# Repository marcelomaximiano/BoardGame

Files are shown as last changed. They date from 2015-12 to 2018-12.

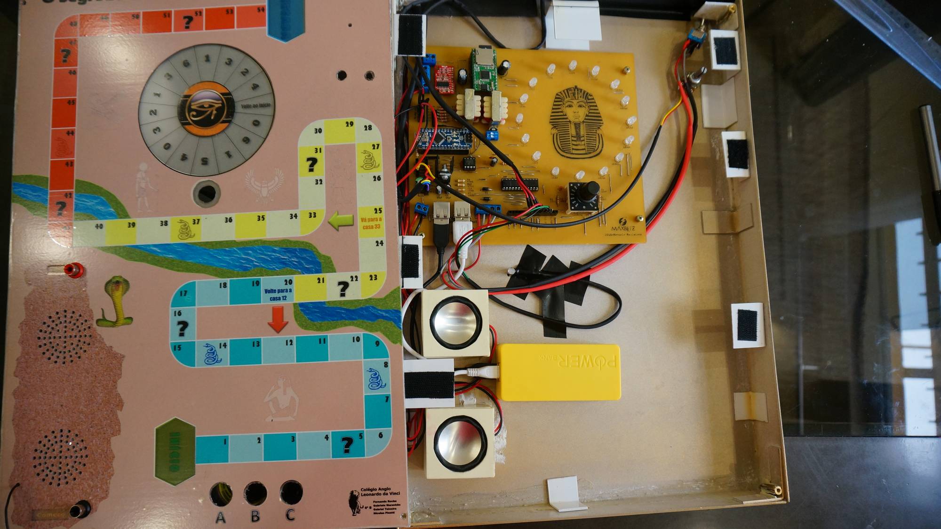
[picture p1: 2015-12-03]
pictures/17-Assembly.jpg

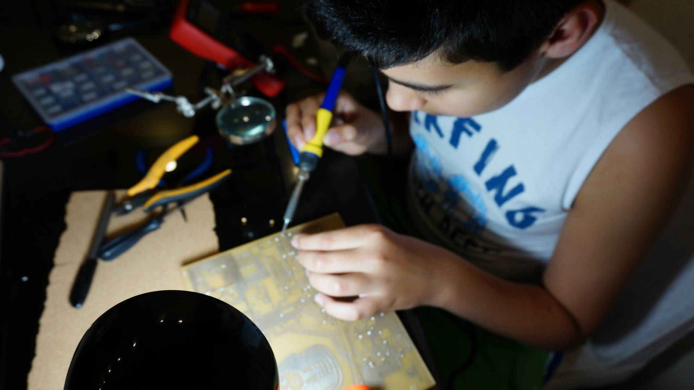
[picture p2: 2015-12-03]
pictures/05-Nick_Soldering.jpg

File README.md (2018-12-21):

# BoardGame
Arduino Board Game: The Pyramid's Secret
<br>
Egypt-themed board game powered by an Arduino Nano, that controls the roulette wheel leds, push buttons, sound player (voices and music), LCD display, etc.

Arduino Project Hub
https://tinyurl.com/arduinopyramidsecret

Make Magazine's article:
https://makezine.com/2016/04/13/these-middle-schoolers-built-custom-arduino-board-game-explore-ancient-egypt/

Videos:
https://www.youtube.com/watch?v=22LTTz00c54
<br>
https://www.youtube.com/watch?v=dJfBCsZCKEY

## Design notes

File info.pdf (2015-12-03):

### O Segredo da Pirâmide

Procuro sempre despertar a curiosidade nos meus filhos, e estimular a ideia de pensar em soluções sem limites: o importante é pensar livremente e criar uma solução, depois, correr atrás do conhecimento necessário para fazer a implementação, afinal a Internet é uma fonte inesgotável de informação, conectando-nos a outros “curiosos” pelo mundo afora, permitindo trocar experiências e inventar coisas novas.

Quando meu filho mais novo, Nícolas de 11 anos, surgiu com a demanda de fazer jogo de tabuleiro para a feira de ciências da escola, logo pensei que seria uma boa oportunidade de incentivar a usar eletrônica. A ideia inicial era só de substituir o dado convencional por um eletrônico com leds. Como o Nícolas é muito criativo, logo começou a “incrementar” a ideia, sugerindo fazer no lugar do dado eletrônico, uma roleta com motor elétrico. Fiz alguns testes e sugeri que seria melhor fazer com leds. Ele gostou da ideia e o escopo estava definido.

Quando as outras crianças do grupo dele se juntaram para começar a fazer o trabalho, orientei-os a projetar um jogo de tabuleiro tradicional, e depois acrescentar a roleta. Bem, a criatividade do Nícolas acabou por “contaminar” os coleguinhas e as ideias começaram a brotar. Como não quis cercear a criatividade deles, o escopo acabou aumentando muito, e ficou um pouquinho mais complexo...

Mas depois de muito trabalho, tudo deu certo e foi um sucesso.

Seguem os detalhes técnicos do projeto:

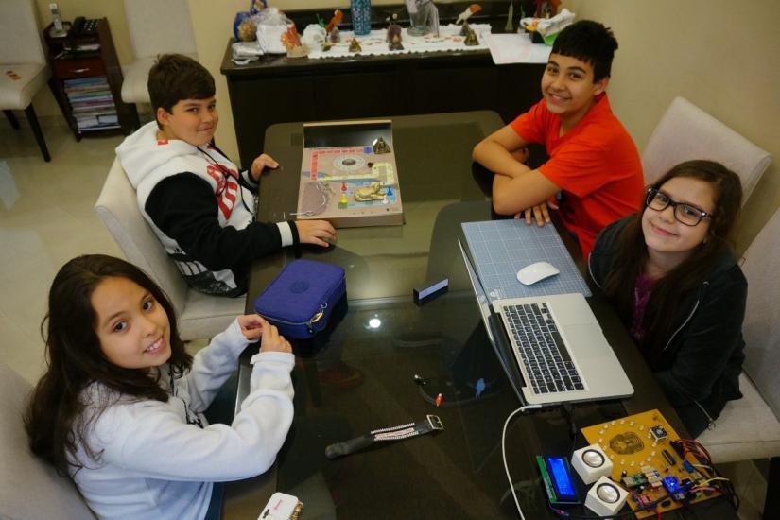
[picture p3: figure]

Equipe-> esquerda: Gabriel Teixeira, Fernanda Rocha / Direita: Nícolas P. Maximiano, Gabriela Maranhão

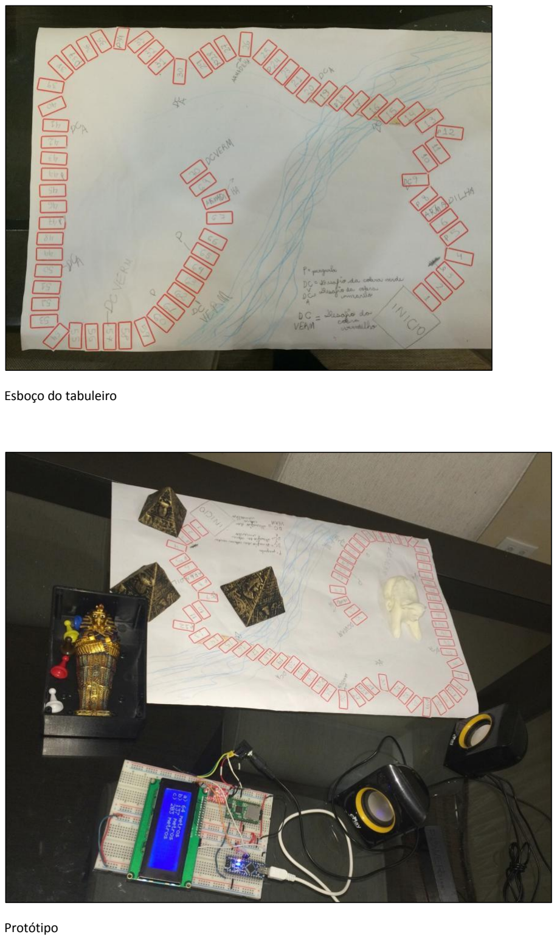
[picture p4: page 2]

Esboço do tabuleiro

Protótipo

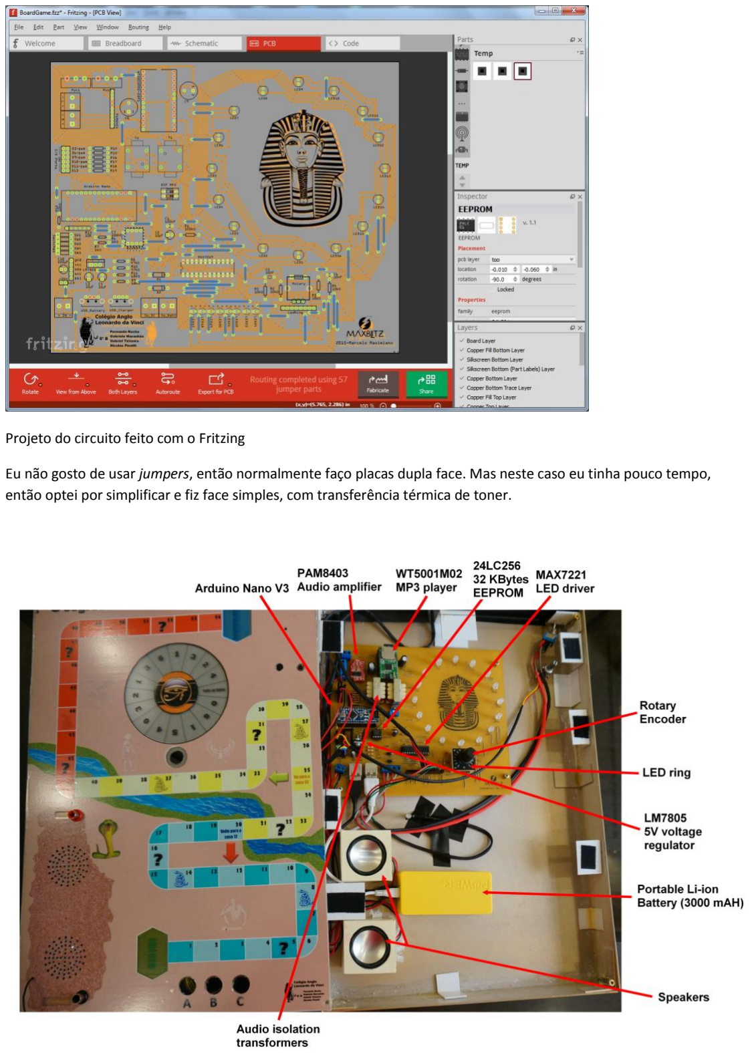
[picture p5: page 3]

Projeto do circuito feito com o Fritzing

Eu não gosto de usar jumpers, então normalmente faço placas dupla face. Mas neste caso eu tinha pouco tempo, então optei por simplificar e fiz face simples, com transferência térmica de toner.

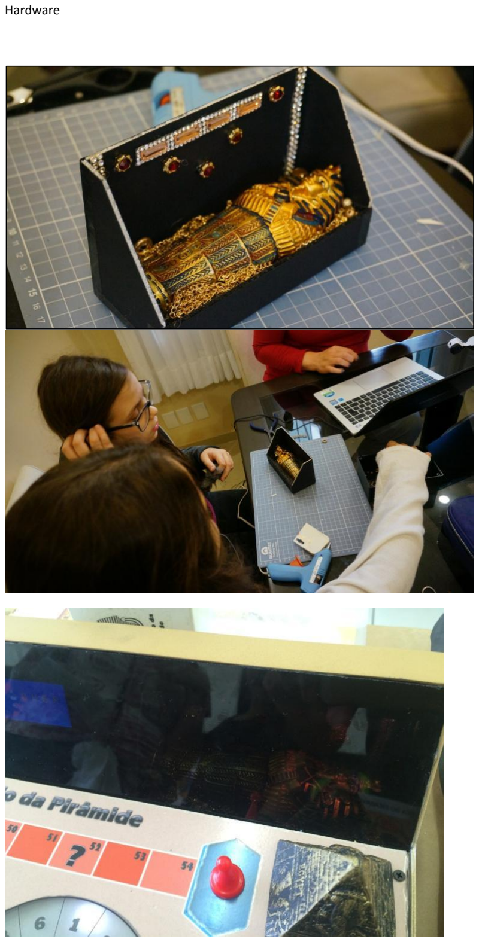
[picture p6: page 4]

Hardware

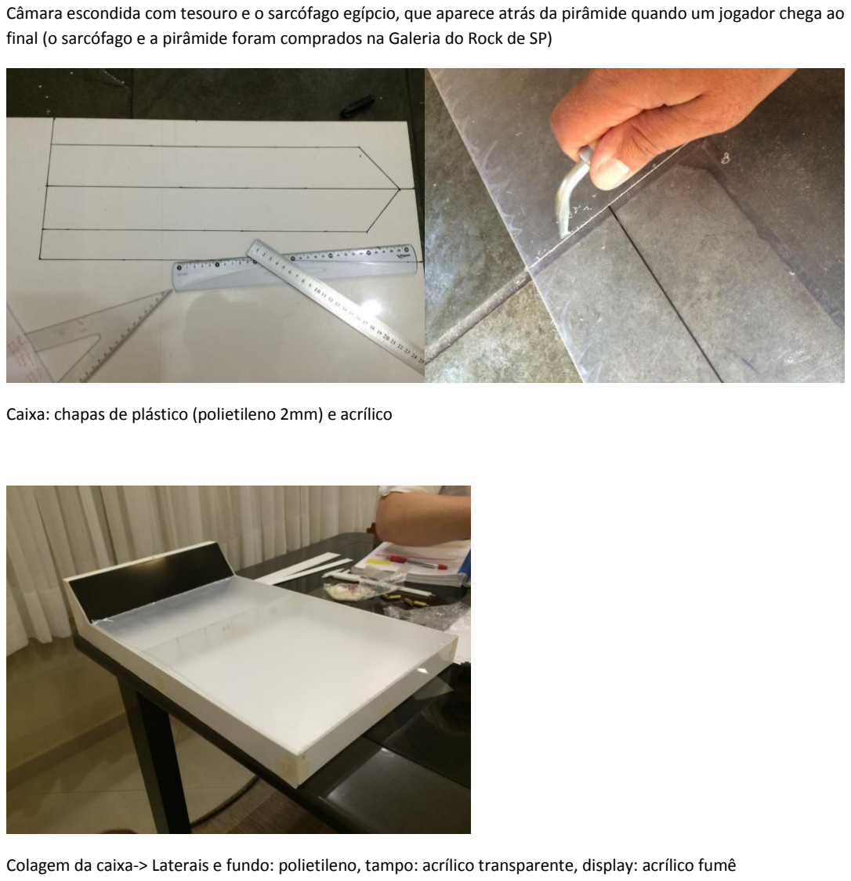
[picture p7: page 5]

Câmara escondida com tesouro e o sarcófago egípcio, que aparece atrás da pirâmide quando um jogador chega ao final (o sarcófago e a pirâmide foram comprados na Galeria do Rock de SP)

Caixa: chapas de plástico (polietileno 2mm) e acrílico

Colagem da caixa-> Laterais e fundo: polietileno, tampo: acrílico transparente, display: acrílico fumê

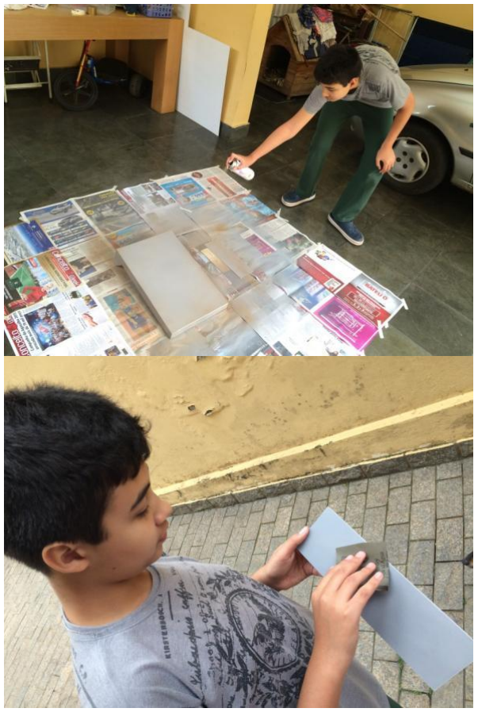
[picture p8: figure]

Pintura

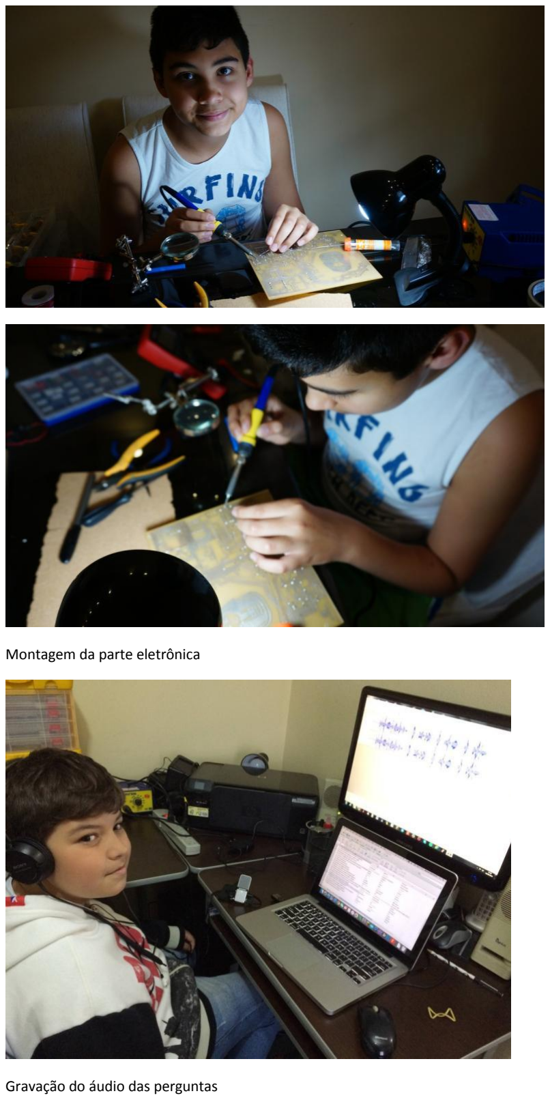
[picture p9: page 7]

Montagem da parte eletrônica

Gravação do áudio das perguntas

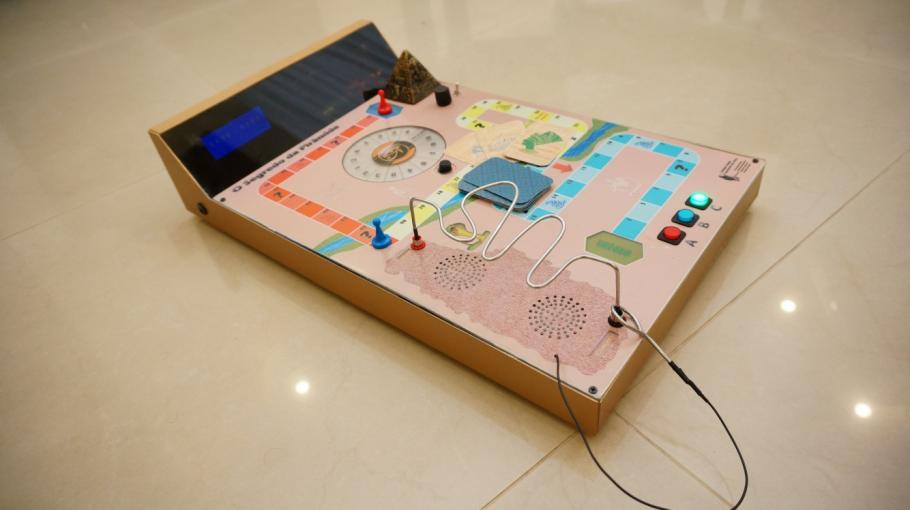
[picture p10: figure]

Desenho do tabuleiro feito no Word e impresso em adesivo vinil

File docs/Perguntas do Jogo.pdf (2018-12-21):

Num | ROM | Page | MP3 Index Time | | Categoria | Pergunta | A | B | C
0 | 00000 | 00001 | 1 | 2 | Fácil | Em qual região fica o Egito? | Norte da África | Oriente Médio | Sul da Ásia
1 | 00160 | 00001 | 2 | 3 | Fácil | Qual é a maior das pirâmides de Gizé? | Quéfren | Miquerinos | Quéops
2 | 00320 | 00001 | 5 | 2 | Fácil | O que é um escaravelho? | Uma pedra preciosa | Um inseto | Um tipo de rato
3 | 00480 | 00001 | 10 | 2 | Fácil | Os Faraós eram : | Amáveis | Soberanos | Legais
4 | 00640 | 00001 | 14 | 3 | Fácil | Quando um egípcio morria ele era: | Cremado | Mumificado | Jogado no Rio Nilo
5 | 00800 | 00002 | 19 | 4 | Fácil | Qual o nome da Raça da Cobra mais perigosa do Egito? | Naja | Sucuri | Titinaboa
6 | 00960 | 00002 | 25 | 2 | Fácil | O faraó era considerado um: | Um rei | Um deus vivo | Uma pessoa importante
7 | 01120 | 00002 | 27 | 3 | Fácil | O que significava o escaravelho para os egípcios? | Renascimento | Guerra | Fortuna
8 | 01280 | 00002 | 28 | 2 | Fácil | Qual era o tipo de governo do egito antigo? | Monarquia | Teocracia | Democracia
9 | 01440 | 00002 | 30 | 4 | Fácil | Qual era o orgão que não era removido durante a mumificação? | Fígado | Cérebro | Coração
10 | 01600 | 00003 | 35 | 2 | Fácil | Qual deus tem cabeça de falcão? | Anúbis | Hórus | Konshu
11 | 01760 | 00003 | 40 | 4 | Fácil | Quem foi falsamente acusado de quebrar o nariz da Esfinge? | Napoleão Bonaparte | Marco Polo | Caesar
12 | 01920 | 00003 | 45 | 3 | Fácil | Qual animal era considerado sagrado? | Gato | Falcão | Chacal
13 | 02080 | 00003 | 47 | 3 | Fácil | Quem era o Deus dos Mortos? | Anúbis | Sobek | Hórus
14 | 02240 | 00003 | 4 | 3 | Média | Para o quê serviam as pirâmides? | Moradia para os faráosTúmulos para faraós Cultos religiosos
15 | 02400 | 00004 | 7 | 3 | Média | O exército do Egito Antigo era formado por: | Soldados Profissionais Escravos | | Pessoas Comuns
16 | 02560 | 00004 | 8 | 3 | Média | Qual o Nome do principal deus do Egito? | Rá | Anubís | Osirís
17 | 02720 | 00004 | 13 | 2 | Média | Quando surgiu a civilização Egipcia? | 30.000 A.C. | 100 A.C. | 3.000 a.C
18 | 02880 | 00004 | 15 | 3 | Média | O nome do protetor das pirâmides? | Esfinge | Anubís | Gib
19 | 03040 | 00004 | 16 | 2 | Média | Onde fica o baixo Egito? | Ao norte do Egito | Ao Sul do Egito | Ao oeste do Egito
20 | 03200 | 00005 | 17 | 4 | Média | O que significa a palavra hieróglifos ? | Escrita dos homens | Escrita sagrada | Escrita do deserto
21 | 03360 | 00005 | 21 | 4 | Média | Quem era o faraó do Egito durante o êxodo dos hebreus? | Seti I | Ramses II | Ramses I
22 | 03520 | 00005 | 22 | 3 | Média | Os Medjay endureciam seus cabelos com: | Cera | Lodo | Barro
23 | 03680 | 00005 | 23 | 3 | Média | Com qual idade Tutancamun se tornou Faraó ? | 10 anos | 9 anos | 11 anos
24 | 03840 | 00005 | 24 | 3 | Média | Qual era o principal problema de saúde dos egipcios? | Problemas RespiratóriosEbola | | Tuberculóse
25 | 04000 | 00006 | 33 | 2 | Média | Quem era o deus do céu? | Rá | Maet | Hórus
26 | 04160 | 00006 | 36 | 3 | Média | Qual era a cor original das pirâmides de Gizé? | Amarela | Cor de areia | Branca
27 | 04320 | 00006 | 37 | 4 | Média | Quantos anos durou a Antiga Civilização Egipcia? | 3000 anos | 1200 anos | 800 anos
28 | 04480 | 00006 | 38 | 3 | Média | Quantas pirâmides foram encontradas no Egito? | 20 | 45 | Mais de 100
29 | 04640 | 00006 | 39 | 5 | Média | O quê os agricultores egípcios faziam na época da cheia do Nilo? | Viajavam de férias | Trabalhavam nos monumentos Iam para escolas de agricultura
30 | 04800 | 00007 | 41 | 3 | Média | Quem foi o último faraó do Egito Antigo? | Cesarión | Tutankamon | Tutmés III
31 | 04960 | 00007 | 42 | 4 | Média | Quem foi o primeiro faraó a ser enterrado no Vale dos Deuses? | Amenófis III | Tutmés I | Ramsés II
32 | 05120 | 00007 | 46 | 4 | Média | Qual faraó construiu o templo de Luxor? | Tutmés IV | Amenófis III | Quéops
33 | 05280 | 00007 | 3 | 3 | Difícil | Qual é a altura da pirâmide de Quéops? | 146 metros | 123 metros | 245 metros
34 | 05440 | 00007 | 6 | 4 | Difícil | Com qual idade morreu o Faraó Tutancâmon? | 18 anos | 36 anos | 67 anos
35 | 05600 | 00008 | 9 | 2 | Difícil | O que signifíca o Olho de Hórus? | Guerra e sangue | Paz e amor | Poder e Proteção
36 | 05760 | 00008 | 11 | 3 | Difícil | O que tinha no chapéu do rei do Norte do Egito? | Um Abutre | Uma cobra | Um elefante
37 | 05920 | 00008 | 12 | 2 | Difícil | Qual o Nome do Pai de Tutankamon?? | Tutmés III | Akhenaton | Oitik
38 | 06080 | 00008 | 18 | 2 | Difícil | Quem decifrou os hieróglifos ? | Pedro de Miercie | Leonardo da VinciJean François Champollion
39 | 06240 | 00008 | 20 | 2 | Difícil | O Deus Sobek é representado por um: | Leão | Crocodilo | Gato
40 | 06400 | 00009 | 26 | 3 | Difícil | Quem destruiu o nariz da Esfinge de Gizé? | Napoleão Bonaparte | Hittler | Cristãos Coptas
41 | 06560 | 00009 | 29 | 3 | Difícil | Em qual época ocorre as cheias do rio nilo? | de junho a setembro | outubro a fevereiromarço a maio
42 | 06720 | 00009 | 31 | 3 | Difícil | Qual era o nome do deus que guardava os pulmões? | Anubís | Osiris | Hapy
43 | 06880 | 00009 | 32 | 2 | Difícil | Qual é o deus da Lua? | Konshu | Ísis | Hórus
44 | 07040 | 00009 | 34 | 2 | Difícil | Quem era o deus da sabedoria? | Toth | Seth | Osíris
45 | 07200 | 00010 | 43 | 4 | Difícil | Quantos filhos teve o faraó Ramsés II? | 90 | 36 | 15
46 | 07360 | 00010 | 44 | 5 | Difícil | O que os egípcios antigos usavam para curar infecções? | Escaravelhos | Pão mofado | Ervas

Arquivo | Tema | Tempo seg
48 | O Segredo da Piramide | 2
49 | Numero de jogadores | 2
50 | Pressione C para iniciar | 3
51 | Parabens voce venceu o jogo | 3
52 | Track 00 | 250
53 | Track 01 | 167
54 | Track 02 | 225
55 | Track 03 | 155
56 | Track 04 | 225
57 | Track 05 | 285
58 | Track 06 | 219
59 | Pergunta | 248
60 | Cobra Intro | 25
61 | Cobra Track | 251
62 | Cobra exito | 344
63 | Cobra Picada | 6
64 | Final | 327

Addr | MSG
10000 | @$#<*/{
10020 | O Segredo
10040 | da Pir$mide
10060 | Pressione C para
10080 | iniciar a partida
10100 | N{mero de jogadores
10120 | Ordem dos jogadores
10140 | Placar geral:
10160 | G A M E O V E R
10180 | Volte ao in<cio!
10200 | Fique na mesma casa!
10220 | Avance X casa
10240 | Volte para a casa 12
10260 | Avance p/ a casa 33
10280 | Parab*ns !!!
10300 | Venceu o jogo !!!
10320 | Desafio da Cobra
10340 | voc/ tem XX segundos
10360 | para atravessar o
10380 | Vale das Cobras !!!
10400 | Para come}ar
10420 | encoste a argola na
10440 | parte met#lica da
10460 | base preta.
10480 | deve pegar uma carta
10500 | e pressionar o bot@o
10520 | da mesma cor.
10540 | deve responder a
10560 | pergunta a seguir:
10580 | Resposta correta !!!
10600 | Avance 1 casa
10620 | Resposta errada !!!
10640 | Retorne 1 casa
10660 | O objetivo * levar
10680 | a argola at* a base
10700 | vermelha, sem tocar
10720 | na cobra met#lica.
10740 | Pode come}ar !!!
10760 | N@o encoste na
10780 | cobra !!!

10800 | Voc/ conseguiu !!!
10820 | A cobra mordeu voc/!

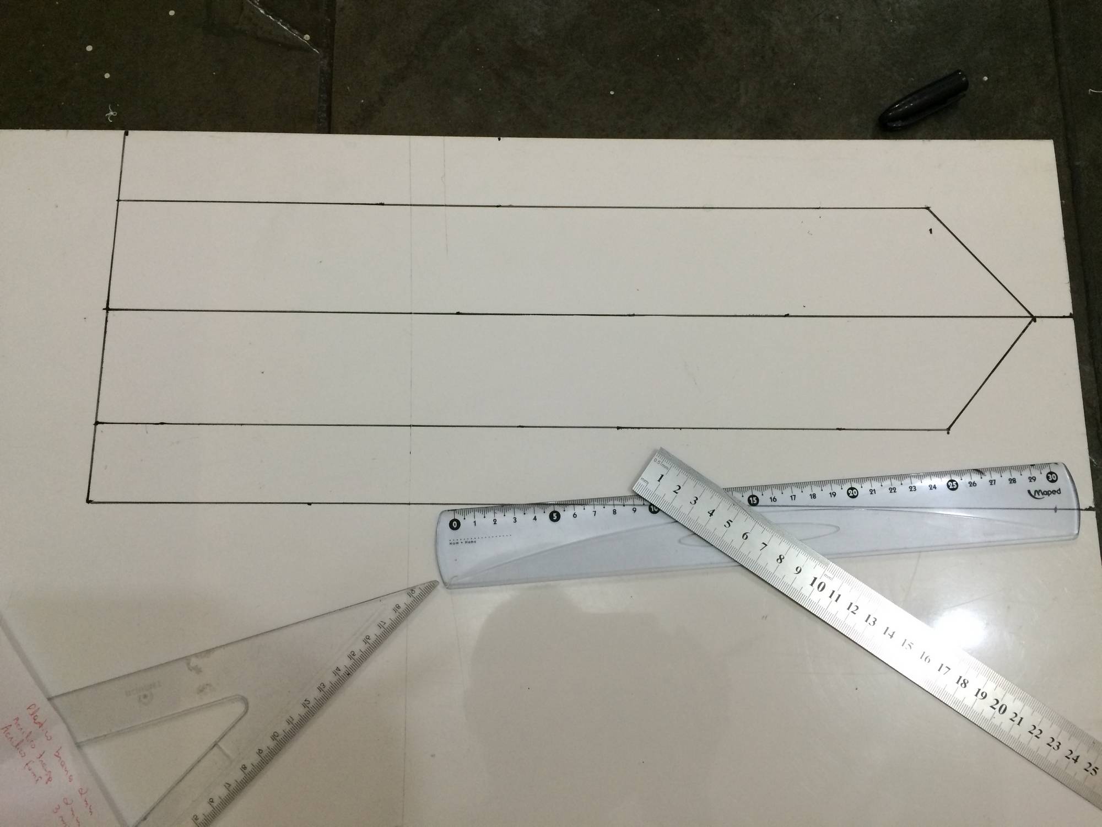
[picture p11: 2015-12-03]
pictures/11-Enclosure_design.jpg

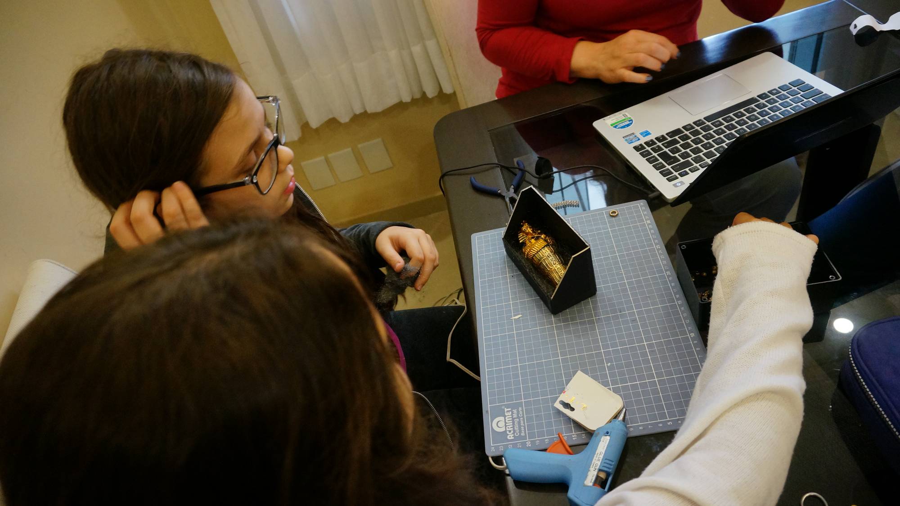
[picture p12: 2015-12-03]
pictures/10-Art_Design.jpg

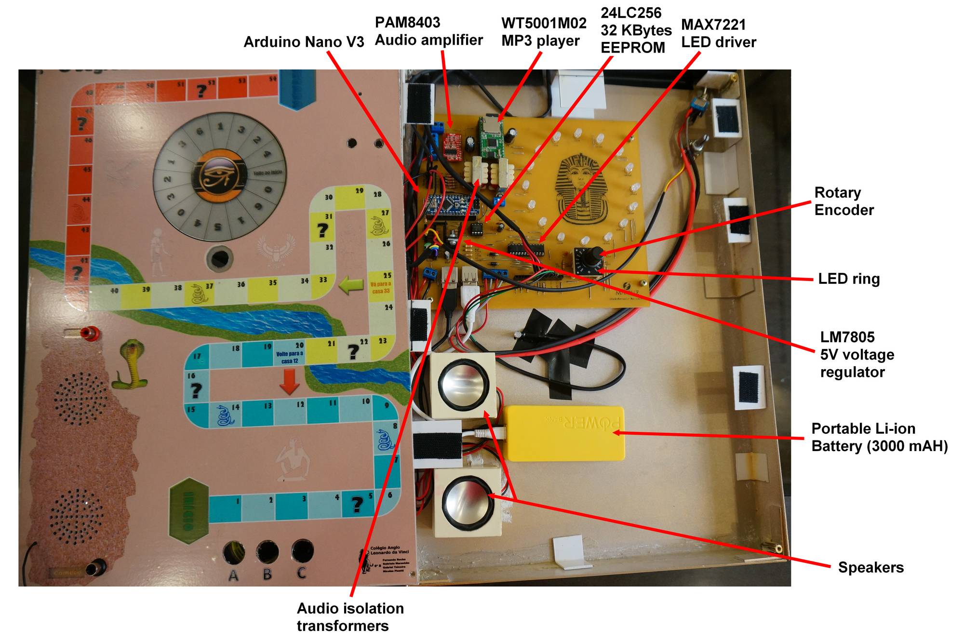
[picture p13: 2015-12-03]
hardware.jpg

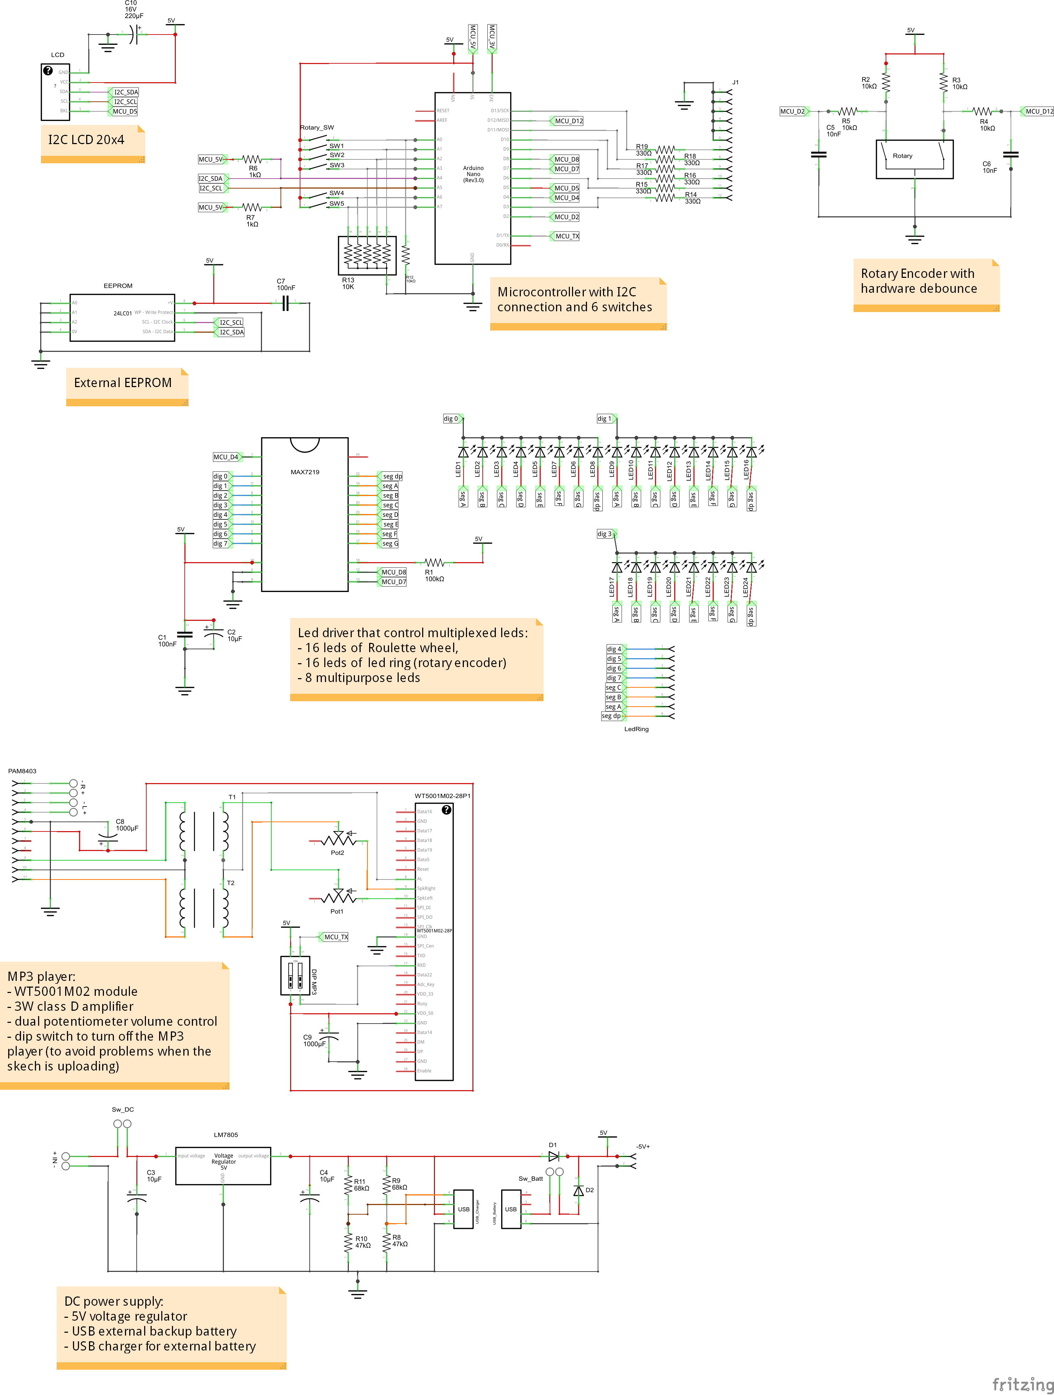
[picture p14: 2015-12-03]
hardware/BoardGame_schem.png

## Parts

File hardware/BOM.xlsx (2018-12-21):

ID | Tipo | Propriedades
Arduino Nano | Microcontrolador | Arduino Nano (Rev3.0) - ATMega328, 16MHz, 32KB flash, 1KB EEPROM, 2KB SRAM, 14 I/O pins
WT5001M02-28P1 | WT5001M02-28P | Módulo MP3 player com socket SD, interface serial
EEPROM | Memória EEPROM | Microchip 24LC256; 32 KBytes; interface I2C; package THT
MAX7221 | Driver para multiplexação de leds | Controlador serial de leds, baixa emisão de EMI
PAM8403 | Amplificador de Audio | Amplificador de audio Class-D, 3W RMS stereo, 5V
C1 | Capacitor cerâmico | Capacitor 100nF; voltage 6.3V; package 100 mil [THT, multilayer]
C2 | Capacitor eletrolítico | Capacitor 10µF; voltage 6.3V; package 100 mil [THT, electrolytic]
C3 | Capacitor eletrolítico | Capacitor 10µF; voltage 6.3V; package 100 mil [THT, electrolytic]
C4 | Capacitor eletrolítico | Capacitor 10µF; voltage 6.3V; package 100 mil [THT, electrolytic]
C5 | Capacitor cerâmico | Capacitor 10nF; voltage 6.3V; package 200 mil [THT, multilayer]
C6 | Capacitor cerâmico | Capacitor 10nF; voltage 6.3V; package 100 mil [THT, multilayer]
C7 | Capacitor cerâmico | Capacitor 100nF; voltage 6.3V; package 200 mil [THT, multilayer]
C8 | Capacitor eletrolítico | Capacitor 1000µF; voltage 20V; package 200 mil [THT, electrolytic]
C9 | Capacitor eletrolítico | Capacitor 1000µF; voltage 16V; package 200 mil [THT, electrolytic]
C10 | Capacitor eletrolítico | Capacitor 220µF; voltage 16V; package 100 mil [THT, electrolytic]
D1 | Diodo | 1N4001
D2 | Diodo | 1N4001
DIP MP3 | Dip switch | Dip switch
J1 | Generic double female header - 12 pins | Header 2.54mm
LCD | Display LCD 20x4 | LCD texto branco sobre fundo azul, 4 linhas com 20 caracteres cada, interface I2C
LED1 | LED | Led branco; 5 mm THT
LED2 | LED | Led branco; 5 mm THT
LED3 | LED | Led branco; 5 mm THT
LED4 | LED | Led branco; 5 mm THT
LED5 | LED | Led branco; 5 mm THT
LED6 | LED | Led branco; 5 mm THT
LED7 | LED | Led branco; 5 mm THT
LED8 | LED | Led branco; 5 mm THT
LED9 | LED | Led branco; 5 mm THT
LED10 | LED | Led branco; 5 mm THT
LED11 | LED | Led branco; 5 mm THT
LED12 | LED | Led branco; 5 mm THT
LED13 | LED | Led branco; 5 mm THT
LED14 | LED | Led branco; 5 mm THT
LED15 | LED | Led branco; 5 mm THT
LED16 | LED | Led branco; 5 mm THT
LED17 | LED button | Led vermelho embutido em pushbutton
LED18 | LED button | Led azul embutido em pushbutton
LED19 | LED button | Led verde embutido em pushbutton
LED20 | LED | Led branco; 10 mm THT
LED21 | LED | Led branco; 10 mm THT
LED22 | LED RGB | Led RGB 5 mm THT - terminal vermelho
LED23 | LED RGB | Led RGB 5 mm THT - terminal verde
LED24 | LED | Led branco; 10 mm THT
LedRing | Led ring | Anel circular de Leds 1.3", 8 pinos multiplexados (4 catodos comuns, 4 anodos comuns)
LM7805 | Regulador de tensão | Regulador de tensão linear 5V; package TO220 [THT]
Pot1 | Potenciometro | Foi substituído por um pot de 10kΩ que controla o volume digitalmente através do microcontrolador
Pot2 | Potenciometro | Foi substituído por um pot de 10kΩ que controla o volume digitalmente através do microcontrolador
R1 | Resistor | Resistor 100kΩ; package THT
R2 | Resistor | Resistor 10kΩ; package THT
R3 | Resistor | Resistor 10kΩ; package THT
R4 | Resistor | Resistor 10kΩ; package THT
R5 | Resistor | Resistor 10kΩ; package THT
R6 | Resistor | Resistor 1kΩ; package THT
R7 | Resistor | Resistor 1kΩ; package THT
R8 | Resistor | Resistor 47kΩ; package THT
R9 | Resistor | Resistor 68kΩ; package THT
R10 | Resistor | Resistor 47kΩ; package THT
R11 | Resistor | Resistor 68kΩ; package THT
R12 | Resistor | Resistor 10kΩ; package THT
R13 | Resistor | Rede de resistores 10kΩ
R14 | Resistor | Resistor 330Ω; package THT
R15 | Resistor | Resistor 330Ω; package THT
R16 | Resistor | Resistor 330Ω; package THT
R17 | Resistor | Resistor 330Ω; package THT
R18 | Resistor | Resistor 330Ω; package THT
R19 | Resistor | Resistor 330Ω; package THT
Rotary | Rotary Encoder | Rotary Encoder
Rotary_SW | Pushbutton | Switch do rotary encoder
SW1 | Pushbutton | Pushbutton NA, led vermelho embutido
SW2 | Pushbutton | Pushbutton NA, led azul embutido
SW3 | Pushbutton | Pushbutton NA, led verde embutido
SW4 | Potenciometro | Potenciometro 10kΩ, volume através de medição da resistência na porta analógica A6
SW5 | Pushbutton | Pushbutton NA
Sw_Batt | Screw terminal - 2 pins | Chave alavanca dupla - terminais 1/2 - bateria
Sw_DC | Screw terminal - 2 pins | Chave alavanca dupla - terminais 3/4 - adaptador DC 12V
T1 | Transformador isolador | Transformador isolador de audio 600 ohms
T2 | Transformador isolador | Transformador isolador de audio 600 ohms
USB_Battery | Conector USB | Bateria externan de Lithion-ion 5V
USB_Charger | Conector USB | Conector USB com 5V para carregar bateria externa
+ IN - | Screw terminal - 2 pins | pin spacing 0.197in (5.0mm); hole size 1.0mm,0.800mm; pins 2; package THT
- L + | Screw terminal - 2 pins | pin spacing 0.197in (5.0mm); hole size 1.0mm,0.800mm; pins 2; package THT
- R + | Screw terminal - 2 pins | pin spacing 0.197in (5.0mm); hole size 1.0mm,0.800mm; pins 2; package THT
-5V+ | Generic female header - 2 pins | Header 2.54mm

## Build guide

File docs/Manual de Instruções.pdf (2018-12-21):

### O SEGREDO DA PIRÂMIDE

Manual de Instruções

Idade mínima: 8 anos
Quantidade de jogadores: mínimo 2 e máximo 5 jogadores.

O tabuleiro deve ser ligado e no caso de bateria estar descarregada, ligar na tomada de 110 volts para recarregá-las.

Existem cinco pinos que devem ser utilizados pelos jogadores. Eles serão deslocados pelo tabuleiro de acordo com o resultado da roleta.

A ordem dos jogadores será determinada pela cor dos pinos:
1º vermelho
2º azul
3º marrom
4º amarelo
5º branco

Como jogar: • Ao ligar o jogo, indique o número de jogadores. • Embaralhe as cartas e deixe-as com a face virada para baixo. • O computador mostrará no display as instruções passo-a-passo. • A roleta será acionada a cada jogada e cada jogador escolhe através do seletor,

a força que deseja acionar a roleta. Ao pressionar o botão seletor, a roleta começará a girar. • Quando a roleta parar, será indicada a ação: avançar um certo número de casas,

não avançar nada ou ainda retornar ao início do jogo.
- Quando um jogador parar em uma casa com o sinal de ? (interrogação), deverá pegar a carta de cima do baralho e pressionar o botão da cor correspondente à figura da carta. O computador selecionará uma pergunta de acordo com o nível de dificuldade indicada pela cor da carta: verde=fácil, azul=médio, vermelho=difícil. • O computador fará uma pergunta e o jogador deverá escolher uma das

alternativas, pressionando um dos botões: A, B ou C. • Se a resposta estiver correta, avança uma casa, senão volta uma casa. • Se o jogador parar em uma casa com a cobra, deverá percorrer o caminho,

deslizando a argola, sem encostar na cobra metálica. Nas casas azuis o jogador terá 50 segundos para percorrer o trecho; nas casas amarelas terá 40 segundos e nas vermelhas 30 segundos. • Se o jogador conseguir chegar ao final sem encostar na cobra, avança uma casa,

senão, volta uma casa. • Existem no tabuleiro casas sinalizadas com atalhos. Caso o jogador avance para

uma casa atalho, o jogador pode avançar ou retornar casas conforme indicado no tabuleiro. • O vencedor será o primeiro jogador que conseguir chegar à pirâmide.

Objetivo:
Encontrar a múmia com o tesouro do faraó.

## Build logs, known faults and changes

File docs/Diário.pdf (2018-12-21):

Diário de bordo.

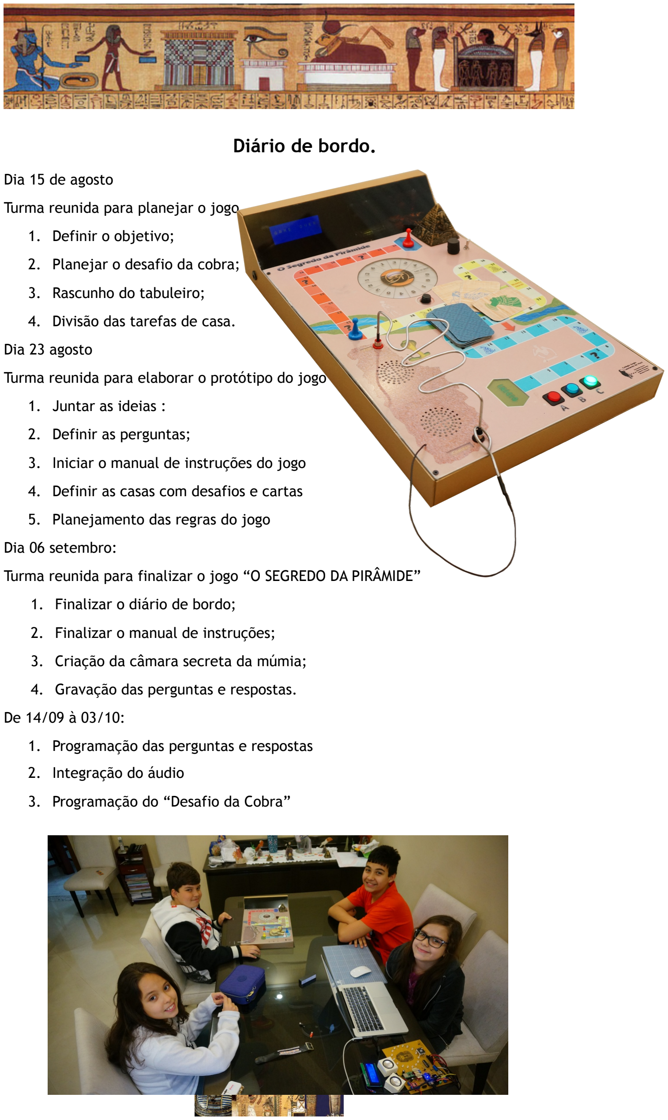
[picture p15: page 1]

Dia 15 de agosto
Turma reunida para planejar o jogo
1. Definir o objetivo;
2. Planejar o desafio da cobra;
3. Rascunho do tabuleiro;
4. Divisão das tarefas de casa.
Dia 23 agosto
Turma reunida para elaborar o protótipo do jogo
1. Juntar as ideias :
2. Definir as perguntas;
3. Iniciar o manual de instruções do jogo
4. Definir as casas com desafios e cartas
5. Planejamento das regras do jogo
Dia 06 setembro:
Turma reunida para finalizar o jogo “O SEGREDO DA PIRÂMIDE”
1. Finalizar o diário de bordo;
2. Finalizar o manual de instruções;
3. Criação da câmara secreta da múmia;
4. Gravação das perguntas e respostas. De 14/09 à 03/10:
1. Programação das perguntas e respostas
2. Integração do áudio
3. Programação do “Desafio da Cobra”

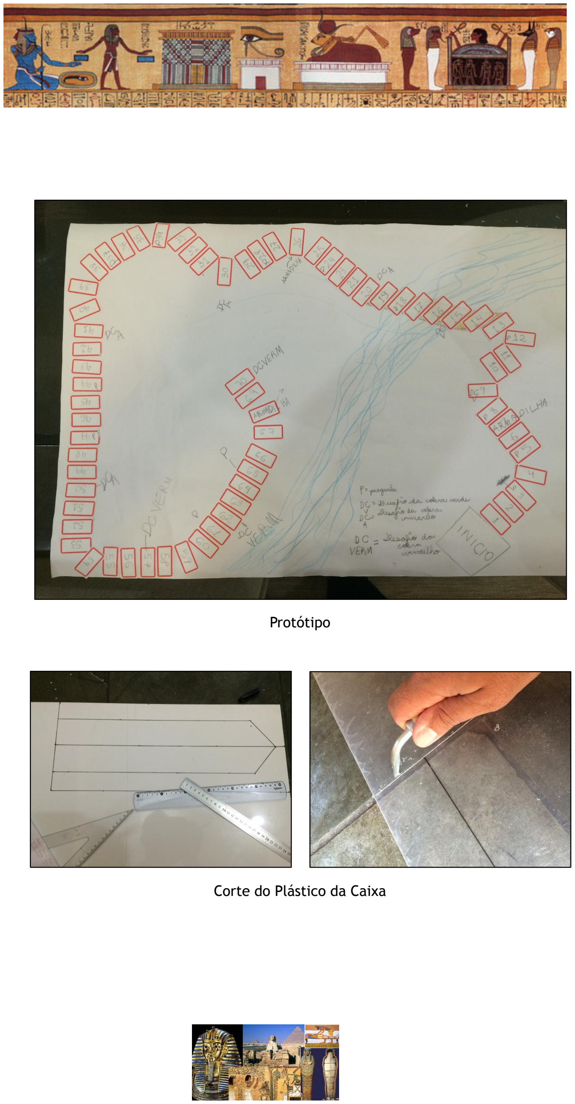
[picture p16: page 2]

Protótipo

Corte do Plástico da Caixa

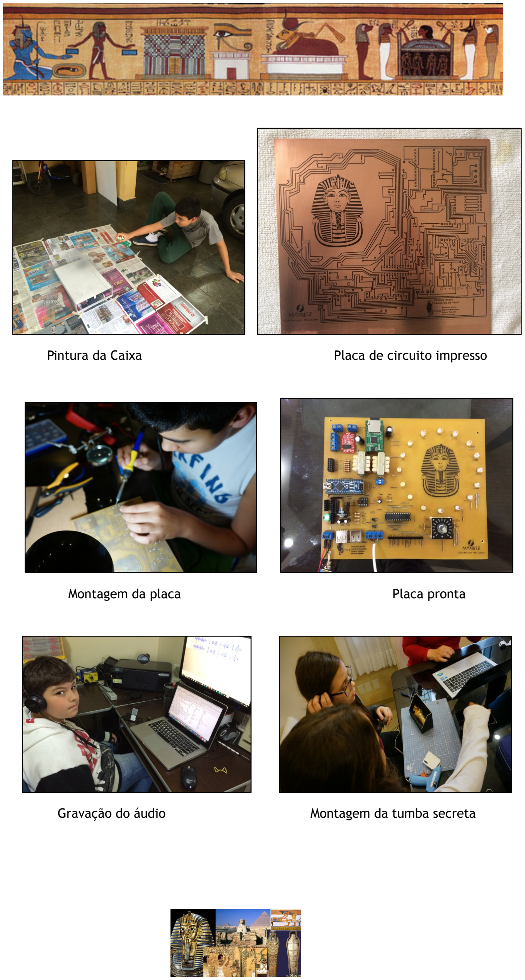
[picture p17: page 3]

Pintura da Caixa | Placa de circuito impresso
Montagem da placa | Placa pronta
Gravação do áudio | Montagem da tumba secreta

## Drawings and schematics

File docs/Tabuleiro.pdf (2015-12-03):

1

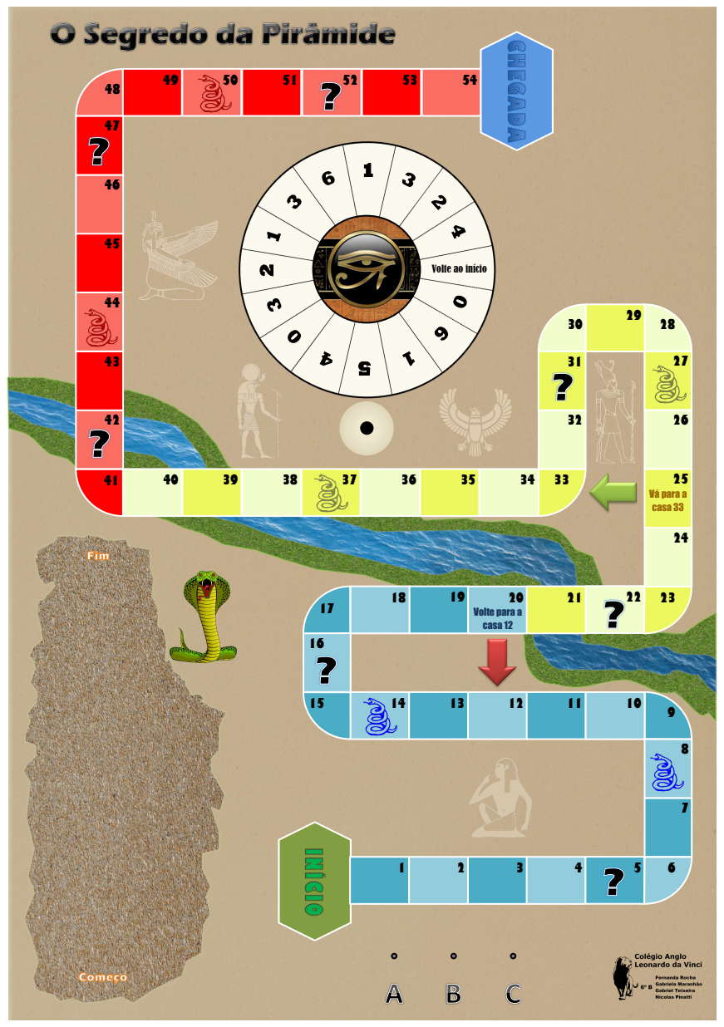
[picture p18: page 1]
Volte para a casa 12; Vá para a casa 33

Volte ao início

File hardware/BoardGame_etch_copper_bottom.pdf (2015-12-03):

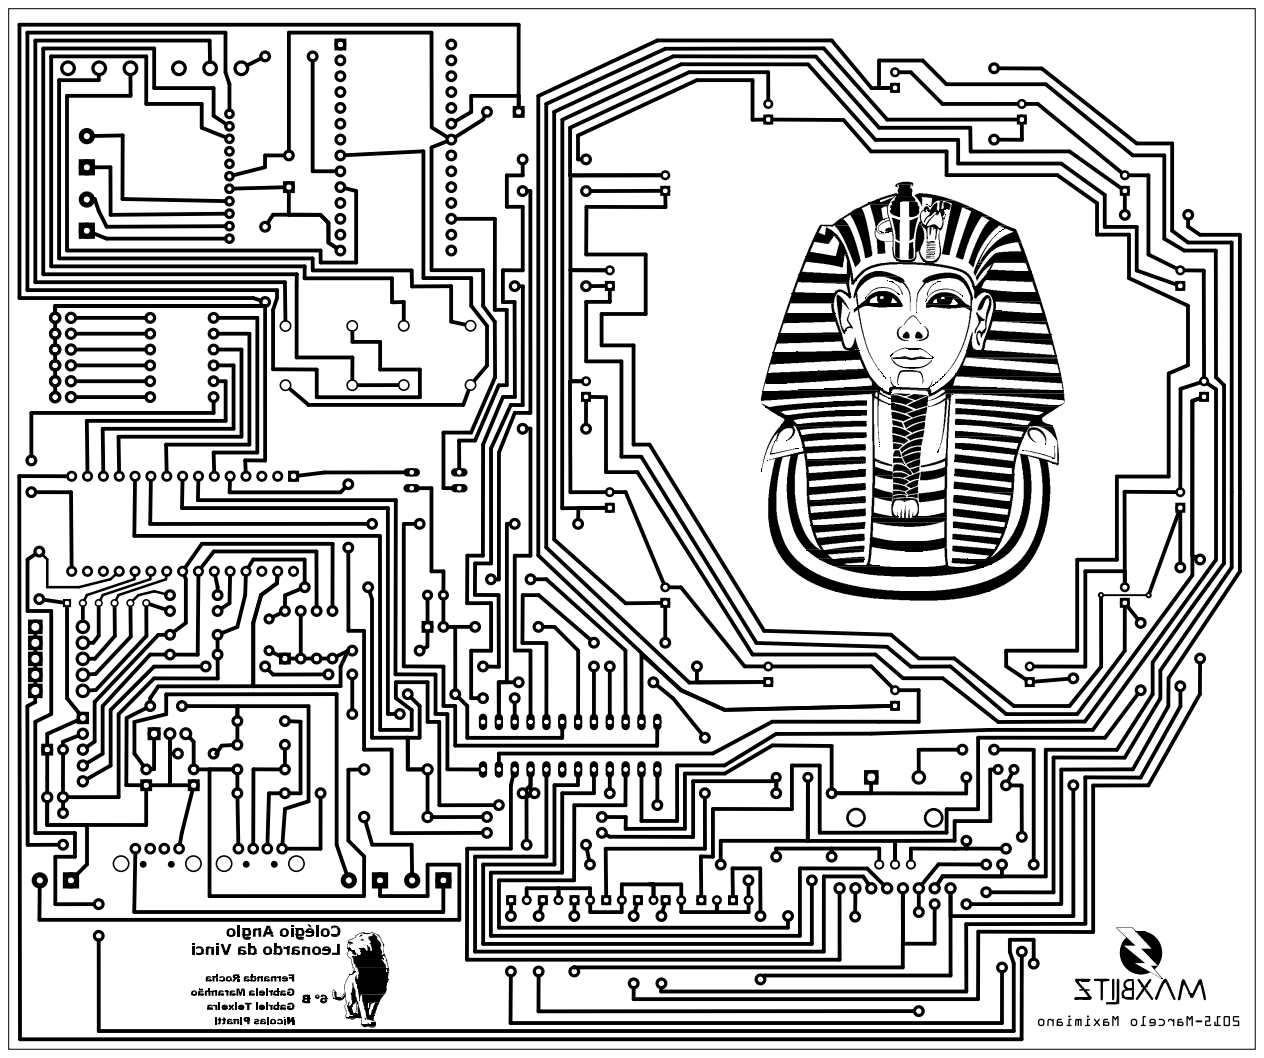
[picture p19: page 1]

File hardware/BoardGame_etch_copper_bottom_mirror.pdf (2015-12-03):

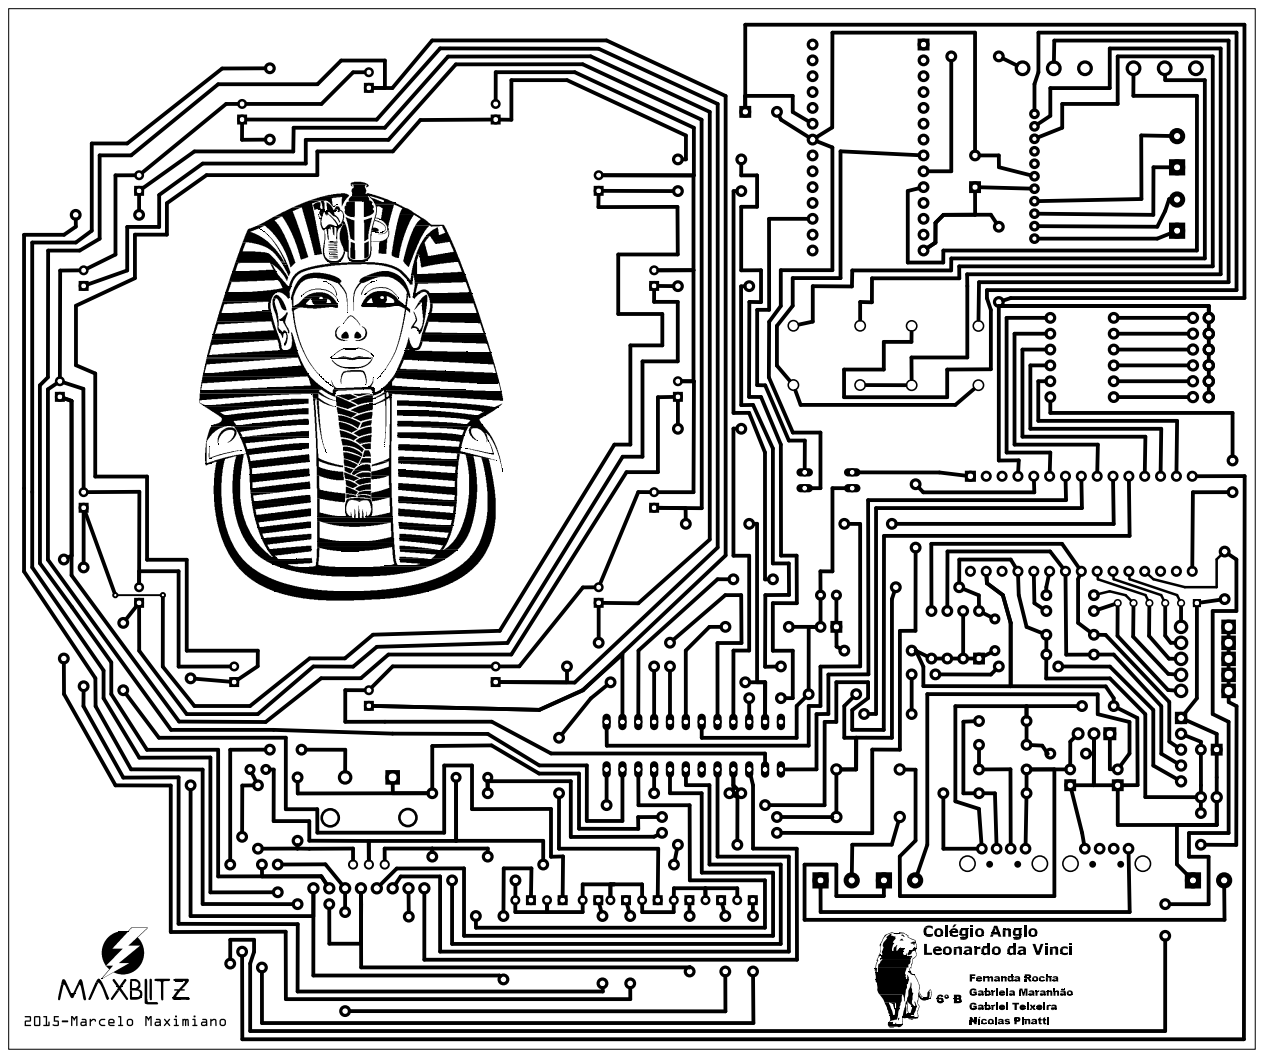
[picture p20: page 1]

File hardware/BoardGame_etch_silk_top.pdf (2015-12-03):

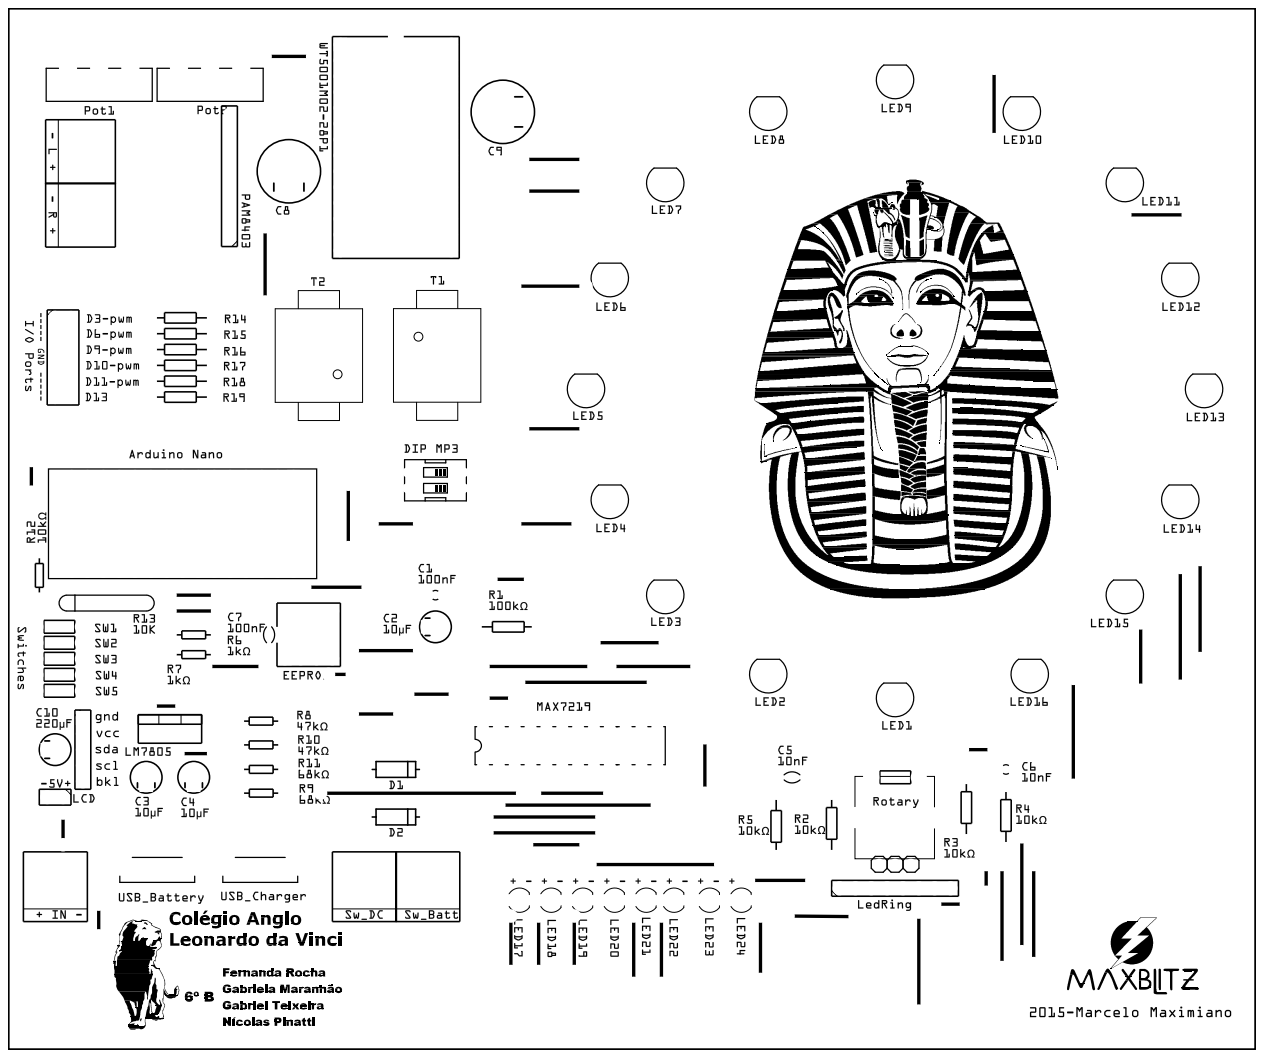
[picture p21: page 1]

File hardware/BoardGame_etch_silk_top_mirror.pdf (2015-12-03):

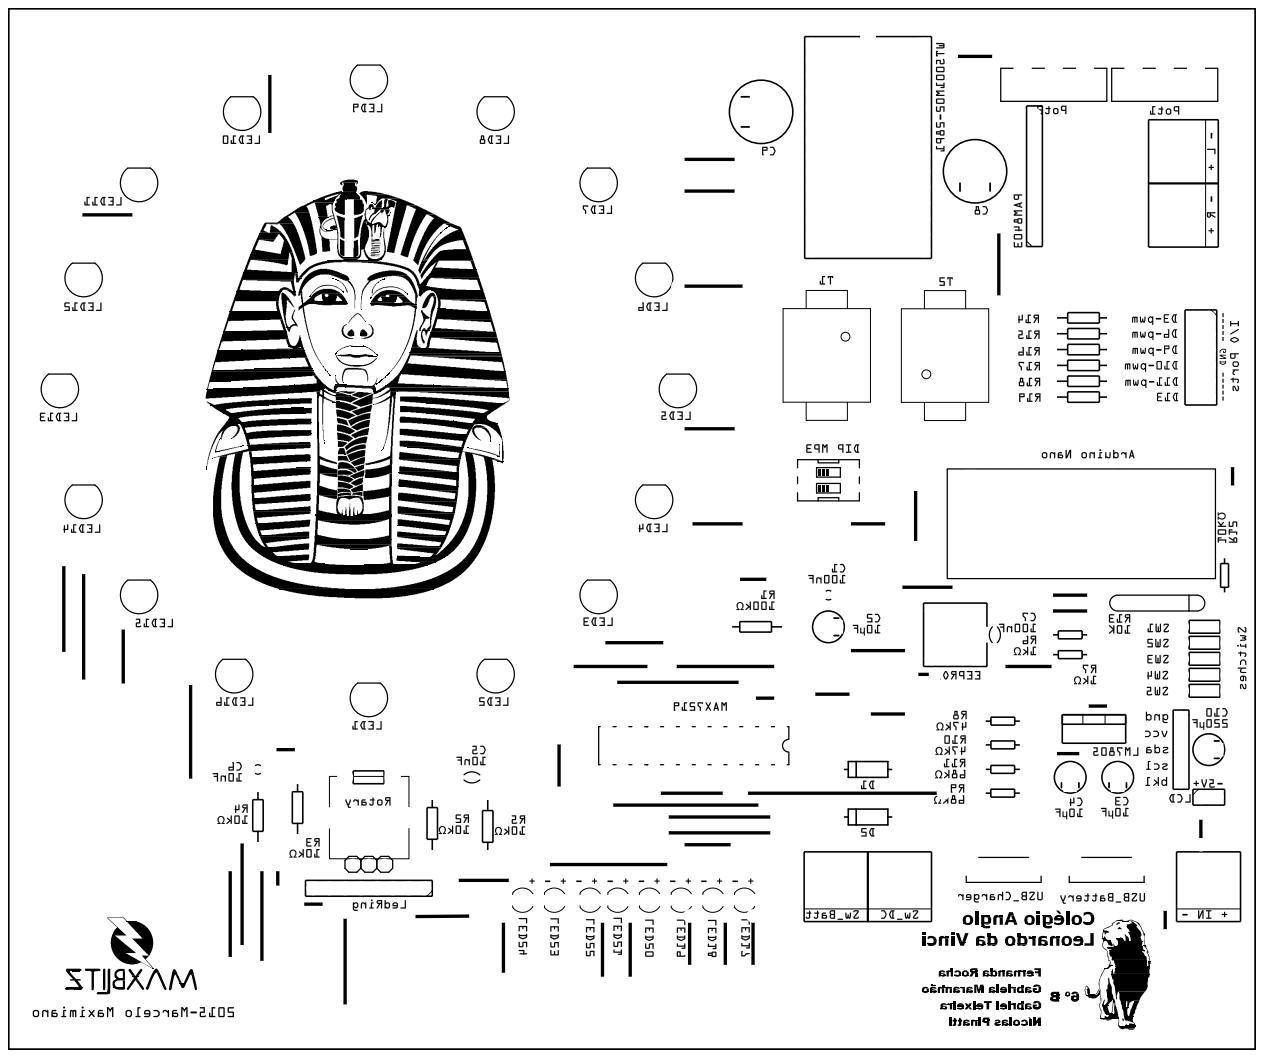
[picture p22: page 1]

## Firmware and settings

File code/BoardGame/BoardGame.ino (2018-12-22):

#include <Wire.h>
#include <LiquidCrystal_I2C.h>
#include "Bounce2.h"

// ***** LCD
#define BACKLIGHT_PIN 5
LiquidCrystal_I2C lcd(0x27, 2, 1, 0, 4, 5, 6, 7, 3, POSITIVE);  // Set the LCD I2C address
#include "LedControlMS.h"
#define DataIn_Pin 4
#define Clock_Pin  7
#define Load_Pin   8

// ***** Leds
LedControl lc = LedControl(DataIn_Pin, Clock_Pin, Load_Pin, 1);
#define ledButtonA    17
#define ledButtonB    18
#define ledButtonC    19
#define ledWhite1     20
#define ledWhite2     21
#define ledSnakeRed   22
#define ledSnakeGreen 23

// ***** Buttons
#define buttonRot  A0
#define buttonA    A1
#define buttonB    A2
#define buttonC    A3
#define snakeWire  9
#define snakeStart 10
#define snakeEnd   11
Bounce debouncerRot = Bounce();
Bounce debouncerA   = Bounce();
Bounce debouncerB   = Bounce();
Bounce debouncerC   = Bounce();
Bounce debouncerSW  = Bounce();
Bounce debouncerS1  = Bounce();
Bounce debouncerS2  = Bounce();

// buttons events
#define evtBtnRot    0
#define evtBtnA      1
#define evtBtnB      2
#define evtBtnC      3
#define evtSW        4
#define evtS1Press   5
#define evtS1Release 6
#define evtS2Press   7
#define evtS2Release 8

// ***** Rotary Encoder
int Rot_Pin1 = 12;
int Rot_Pin2 = 2;
int encoderValue = 1;
int lastEncoded = LOW;

// ***** Sound Volume
int soundVolume = 20;  // max 31

// ***** Sound Track
#define soundTrackStart 52
#define soundTrackEnd   58
int soundTrack = soundTrackStart;


// ***** Acentos para mensagens gerais
char strAccents[11] = "          ";

void setup()
{
  Serial.begin(9600);
  Wire.begin();

  uint32_t seed = millis();
  randomSeed(seed);

  lc.shutdown(0, false);
  /* Set the brightness to a medium values */
  lc.setIntensity(0, 12);
  /* and clear the display */
  lc.clearDisplay(0);

  // initialize Rotary Encoder
  pinMode (Rot_Pin1, INPUT);
  pinMode (Rot_Pin2, INPUT);

  // inicializa os botoes
  initButton(buttonRot);
  initButton(buttonA);
  initButton(buttonB);
  initButton(buttonC);
  initButton(snakeWire);
  initButton(snakeStart);
  initButton(snakeEnd);

  // toca o som de introduçao
  getSoundVolume();
  soundPlay(48);
  
  // Switch on the backlight
  pinMode (BACKLIGHT_PIN, OUTPUT);
  digitalWrite(BACKLIGHT_PIN, HIGH);
  lcd.begin(20, 4);              // initialize the lcd
  lcd.clear();
  lcd.setCursor(0, 1);
  displayRomStr(10020);     // O Segredo
  loadChars(strAccents);
  lcd.setCursor(0, 2);
  displayRomStr(10040);     // da Piramide
  delay(3000);
}

// Timers
unsigned long timer1 = 0;
unsigned long timer1_interval = 1000;
unsigned long timer2 = 0;
unsigned long timer2_interval = 300;
unsigned long timer3 = 0;
unsigned long timer3_interval = 20000;
unsigned long timer4 = 0;
unsigned long timer4_interval = 30000;

// etapas do jogo
#define HowManyPlayers 1
#define Begin          2
#define Roulette       3
#define GameOver       4

bool gameOver = false;

int NumberPlayers = 2;
int buttonPressed = -1;

char* players[]   = { "vermelho", "azul", "marrom", "amarelo", "branco" };
int rouletteVal[] = { 5, 4, 0, 3, 2, 1, 3, 6, 1, 3, 2, 4, -1, 0, 6, 1 };
int playersPos[]  = { 0, 0, 0, 0, 0 };
int playersPenalty[]  = { 0, 0, 0, 0, 0 };

int currentPlayer = 0;
int roulettePos = 1;

// niveis de dificuldade das perguntas
#define questionLevel01 1
#define questionLevel02 1
#define questionLevel03 1

void loop()
{
  unsigned long currentMillis = millis();

  // toca o som Numero de Jogadores
  soundPlay(49);
  
  // numero de jogadores
  ligaLed(ledButtonA, true);
  ligaLed(ledButtonB, true);
  ligaLed(ledButtonC, true);

  digitalWrite ( BACKLIGHT_PIN, HIGH );
  loadChars(strAccents);
  lcd.clear();
  lcd.setCursor(0, 0);
  displayRomStr(10100);     // Numero de jogadores
  lcd.setCursor(0, 1);
  char str[10];
  sprintf(str, "%1d", NumberPlayers);
  lcd.write(str);
  lcd.setCursor(9, 1);
  lcd.write("A) +");
  lcd.setCursor(9, 2);
  lcd.write("B) -");
  lcd.setCursor(9, 3);
  lcd.write("C) confirma");
  buttonPressed = -1;

  while (true)
  {
    buttonPressed = getButton();

    if (buttonPressed == evtBtnA) {
      NumberPlayers++;
      if (NumberPlayers > 5) {
        NumberPlayers = 5;
      }
    }
    if (buttonPressed == evtBtnB) {
      NumberPlayers--;
      if (NumberPlayers < 2) {
        NumberPlayers = 2;
      }
    }

    if (buttonPressed != -1) {
      lcd.setCursor(0, 1);
      char str[10];
      sprintf(str, "%1d", NumberPlayers);
      lcd.write(str);
    }

    if (buttonPressed == evtBtnC) {
      uint32_t seed = millis();
      randomSeed(seed);
      lcd.clear();
      ligaLed(ledButtonA, false);
      ligaLed(ledButtonB, false);
      ligaLed(ledButtonC, false);
      displayPlayers();
      waitConfirm(3000);
      displayPressToBegin();
      game();
      break;
    }
    buttonPressed = -1;
  }
}

void displayPressToBegin() {
  digitalWrite(BACKLIGHT_PIN, HIGH);

  ligaLed(ledButtonA, false);
  ligaLed(ledButtonB, false);
  ligaLed(ledButtonC, false);

  // toca o som Pressione C para iniciar
  soundPlay(50);

  lcd.clear();
  lcd.setCursor(0, 0);
  displayRomStr(10060);     // Pressione C para
  lcd.setCursor(0, 1);
  displayRomStr(10080);     // iniciar a partida

  waitConfirm(0);
}

void game() {
  int rotV = lastEncoded;

  // reinicializa a posição dos jogadores
  for (int i = 0; i <= 4; i++) {
    playersPos[i] = 0;
    playersPenalty[i]  = 0;
  }
  currentPlayer = 0;
  gameOver = false;

  // toca a musica de abertura
  soundTrack = soundTrackStart;
  soundPlay(soundTrack);

  while (true)
  {
    turnOffAllLeds();
    ligaLed(ledButtonA, false);
    ligaLed(ledButtonB, false);
    ligaLed(ledButtonC, true);

    digitalWrite(BACKLIGHT_PIN, HIGH);
    lcd.clear();
    displayPlayer();
    lcd.setCursor(0, 1);
    lcd.write("Gire a roleta!");
    ligaLed(roulettePos, true);

    while (true)
    {
      // **********  Rotary Encoder
      readRotaryEncoder();
      if (rotV != lastEncoded) {
        ringSeq(encoderValue);
      }

      buttonPressed = getButton();

      if ((buttonPressed == evtBtnRot) || (buttonPressed == evtBtnC)) {
        loadChars(strAccents);
        lcd.clear();
        ligaLed(ledButtonA, false);
        ligaLed(ledButtonB, false);
        ligaLed(ledButtonC, false);
        spinRoulette();

        lcd.clear();
        lcd.setCursor(0, 0);
        displayPlayer();

        if (roulettePos < 1) roulettePos = 1;
        if (roulettePos > 16) roulettePos = 16;
        
        int rv = rouletteVal[roulettePos - 1];

        if (rv == -1) {
          playersPos[currentPlayer] = 0;
          lcd.setCursor(0, 1);
          displayRomStr(10180);     // Volte ao inicio!
        }
        else if (rv == 0) {
          lcd.setCursor(0, 1);
          displayRomStr(10200);     // Fique na mesma casa!
        }
        else {
          playersPos[currentPlayer] = playersPos[currentPlayer] + rv;
          if (playersPos[currentPlayer] > 54) {
            playersPos[currentPlayer] = 55;
          }

          lcd.setCursor(0, 1);
          displayRomStr(10220);     // Avance X casa
          char str[10];
          sprintf(str, "%1d", rv);
          lcd.setCursor(7, 1);
          lcd.write(str);
          if (rv > 1) {
            lcd.setCursor(13, 1);
            lcd.write("s");
          }

          waitConfirm(2000);

          switch (playersPos[currentPlayer]) {
            case 5: case 16: case 22: case 31: case 42: case 47: case 52:
              displayGetCard();
              break;
            case 8: case 14:
              snake(50);
              break;
            case 27: case 37:
              snake(40);
              break;
            case 44: case 50:
              snake(30);
              break;
            case 20:
              delay(2000);
              playersPos[currentPlayer] = 12;
              lcd.setCursor(0, 1);
              displayRomStr(10240);     // Volte para a casa 12
              break;
            case 25:
              delay(2000);
              playersPos[currentPlayer] = 33;
              lcd.setCursor(0, 1);
              displayRomStr(10260);     // Avance p/ a casa 33
              break;
          }

          if (playersPos[currentPlayer] == 55) {
            delay(2000);
            // toca a musica final
            soundPlay(64);
            lcd.clear();
            lcd.setCursor(0, 0);
            displayRomStr(10280);     // Parabens!!!
            lcd.setCursor(0, 1);
            displayPlayer();
            lcd.setCursor(0, 2);
            displayRomStr(10300);     // Venceu o jogo !!!
            ligaLed(ledWhite1, true);
            ligaLed(ledWhite2, true);
            gameOver = true;
            delay(5000);
            displayGameOver();
            break;
          }
        }
        waitConfirm(3000);
        displayPos();
        waitConfirm(3000);

        currentPlayer++;
        if (currentPlayer > NumberPlayers - 1) {
          currentPlayer = 0;
        }
        break;
      }
    }
    if (gameOver) {
      break;
    }
  }
  buttonPressed = -1;
}

void snake(int time) {
  loadChars(strAccents);

  // toca o som de introduçao
  soundPlay(60);
  
  turnOffAllLeds();
  ligaLed(ledSnakeGreen, true);

  lcd.clear();
  lcd.setCursor(0, 1);
  displayRomStr(10320);     // Desafio da Cobra
  delay(2000);

  lcd.clear();
  lcd.setCursor(0, 0);
  displayRomStr(10660);     // O objetivo é levar
  lcd.setCursor(0, 1);
  displayRomStr(10680);     // a argola até a base
  lcd.setCursor(0, 2);
  displayRomStr(10700);     // vermelha, sem encostar
  lcd.setCursor(0, 3);
  displayRomStr(10720);     // na cobra metálica.
  waitConfirm(5000);

  lcd.clear();
  displayPlayer();
  lcd.write(",");
  lcd.setCursor(0, 1);
  displayRomStr(10340);     // voce tem XX segundos
  lcd.setCursor(9, 1);
  lcd.print(time, DEC);
  lcd.setCursor(0, 2);
  displayRomStr(10360);     // para atravessar o
  lcd.setCursor(0, 3);
  displayRomStr(10380);     // Vale das Cobras !!!
  waitConfirm(5000);

  lcd.clear();
  lcd.setCursor(0, 0);
  displayRomStr(10400);     // Para começar
  lcd.setCursor(0, 1);
  displayRomStr(10420);     // encoste a argola na
  lcd.setCursor(0, 2);
  displayRomStr(10440);     // parte metalica da
  lcd.setCursor(0, 3);
  displayRomStr(10460);     // base preta.
  buttonPressed = -1;

  while (true) {
    buttonPressed = getButton();
    if (buttonPressed == evtS1Press) {
      break;
    }
  }

  lcd.clear();
  lcd.setCursor(0, 0);
  displayRomStr(10740);     // Pode começar !!!
  buttonPressed = -1;

  while (true) {
    buttonPressed = getButton();
    if (buttonPressed == evtS1Release) {
      break;
    }
  }

  // toca a trilha da cobra
  soundPlay(61);

  lcd.clear();
  lcd.setCursor(0, 0);
  displayRomStr(10760);     // Não encoste
  lcd.setCursor(0, 1);
  displayRomStr(10780);     // na cobra!

  unsigned long currentMillis = millis();
  timer2 = currentMillis;
  timer2_interval = 1000;
  buttonPressed = -1;

  while (true) {
    currentMillis = millis();
    buttonPressed = getButton();

    if (buttonPressed == evtS2Press) {
      // toca a trilha da cobra exito
      soundPlay(62);
      playersPos[currentPlayer] = playersPos[currentPlayer] + 1;
      lcd.clear();
      lcd.setCursor(0, 0);
      displayRomStr(10280);     // Parabéns !!!
      lcd.setCursor(0, 1);
      displayRomStr(10800);     // Você conseguiu !!!
      lcd.setCursor(0, 3);
      displayRomStr(10600);     // Avance uma casa
      lcd.write("Avance 1 casa.");
      break;
    }

    if ((buttonPressed == evtSW) || (time < 0)) {
      // toca o som da mordida da cobra
      soundPlay(63);
      playersPos[currentPlayer] = playersPos[currentPlayer] - 1;
      ligaLed(ledSnakeRed, true);
      ligaLed(ledSnakeGreen, false);
      lcd.clear();
      lcd.setCursor(0, 0);
      displayRomStr(10820);     // A cobra mordeu você!
      lcd.setCursor(0, 2);
      displayRomStr(10640);     // Retorne uma casa
      break;
    }

    if (currentMillis - timer2 > timer2_interval) {
      lcd.setCursor(0, 3);
      lcd.write("Tempo : ");
      lcd.print(time, DEC);
      lcd.write(" ");
      timer2 = currentMillis;
      time--;
    }
  }

  waitConfirm(3000);
  turnOffAllLeds();

  // toca a proxima musica
  soundTrack++;
  if (soundTrack > soundTrackEnd) {
    soundTrack = soundTrackStart;
  }
  soundPlay(soundTrack);
}

void ligaLed(int i, bool flag) {
  int dig = 0;
  int ld = 0;

  if ((i >= 1) && (i <= 8)) {
    dig = 0;
    if (i == 6) {
      i = 7;
    }
    else if (i == 7) {
      i = 6;
    }
    if (i == 8) {
      ld = 0;
    }
    else {
      ld = i;
    }
  }
  else if ((i >= 9) && (i <= 16)) {
    dig = 1;
    i = i - 8;
    if (i == 8) {
      ld = 0;
    }
    else {
      ld = i;
    }
  }
  else if ((i >= 17) && (i <= 24)) {
    dig = 3;
    i = i - 16;
    if (i == 8) {
      ld = 0;
    }
    else {
      ld = i;
    }
  }

  lc.setLed(0, dig, ld, flag);
}

void clearRing() {
  for (int r = 4; r <= 7; r++) {
    lc.setRow(0, r, B00000000);
  }
}

void ringSeq(int n) {
  clearRing();
  for (int c = 1; c <= n; c++) {
    ring(c);
  }
}

void ring(int n) {
  int dig = 0;
  int ld = 0;

  switch (n) {
    case 0:
      dig = 7;
      ld = 3;
      break;
    case 1 ... 4:
      dig = 4;
      ld = n - 1;
      break;
    case 5 ... 8:
      dig = 5;
      ld = n - 5;
      break;
    case 9 ... 12:
      dig = 6;
      ld = n - 9;
      break;
    case 13 ... 15:
      dig = 7;
      ld = n - 13;
      break;
    default:
      break;
  }
  lc.setLed(0, dig, ld, true);
}

void readRotaryEncoder() {
  int n = LOW;
  n = digitalRead(Rot_Pin1);
  if ((lastEncoded == LOW) && (n == HIGH)) {
    if (digitalRead(Rot_Pin2) == LOW) {
      encoderValue--;
    }
    else {
      encoderValue++;
    }
    if (encoderValue > 15) encoderValue = 15;
    if (encoderValue < 1) encoderValue = 1;
  }
  lastEncoded = n;
}

void initButton(int pinButton) {
  pinMode(pinButton, INPUT);
  digitalWrite(pinButton, HIGH);
  pinMode(pinButton, INPUT_PULLUP);

  switch (pinButton) {
    case buttonRot:
      debouncerRot.attach(pinButton);
      debouncerRot.interval(5); // interval in ms
      break;
    case buttonA:
      debouncerA.attach(pinButton);
      debouncerA.interval(5); // interval in ms
      break;
    case buttonB:
      debouncerB.attach(pinButton);
      debouncerB.interval(5); // interval in ms
      break;
    case buttonC:
      debouncerC.attach(pinButton);
      debouncerC.interval(5); // interval in ms
      break;
    case snakeWire:
      debouncerSW.attach(pinButton);
      debouncerSW.interval(5); // interval in ms
      break;
    case snakeStart:
      debouncerS1.attach(pinButton);
      debouncerS1.interval(5); // interval in ms
      break;
    case snakeEnd:
      debouncerS2.attach(pinButton);
      debouncerS2.interval(5); // interval in ms
      break;
    default:
      break;
  }
}

// verifica qual botão foi acionado
int getButton() {
  // evento do botao Rotary Encoder
  debouncerRot.update();
  static int lastBtnRotVal = -1;
  int BtnRotVal = debouncerRot.read();
  if (BtnRotVal != lastBtnRotVal) {
    lastBtnRotVal = BtnRotVal;
    if ( BtnRotVal == LOW ) {
      // evento Release
    }
    else {
      // evento Press
      return evtBtnRot;
    }
  }
  // evento do botao A
  debouncerA.update();
  static int lastBtnAVal = -1;
  int BtnAVal = debouncerA.read();
  if (BtnAVal != lastBtnAVal) {
    lastBtnAVal = BtnAVal;
    if ( BtnAVal == LOW ) {
      // evento Release
    }
    else {
      // evento Press
      return evtBtnA;
    }
  }

  // evento do botao B
  debouncerB.update();
  static int lastBtnBVal = -1;
  int BtnBVal = debouncerB.read();
  if (BtnBVal != lastBtnBVal) {
    lastBtnBVal = BtnBVal;
    if ( BtnBVal == LOW ) {
      // evento Release
    }
    else {
      // evento Press
      return evtBtnB;
    }
  }

  // evento do botao C
  debouncerC.update();
  static int lastBtnCVal = -1;
  int BtnCVal = debouncerC.read();
  if (BtnCVal != lastBtnCVal) {
    lastBtnCVal = BtnCVal;
    if ( BtnCVal == LOW ) {
      // evento Release
    }
    else {
      // evento Press
      return evtBtnC;
    }
  }

  // evento encostar a argola no arame
  debouncerSW.update();
  static int lastBtnSWVal = -1;
  int BtnSWVal = debouncerSW.read();
  if (BtnSWVal != lastBtnSWVal) {
    lastBtnSWVal = BtnSWVal;
    if ( BtnSWVal == HIGH ) {
      // evento Release
    }
    else {
      // evento Press
      return evtSW;
    }
  }

  // evento encostar a argola no ponto de inicio
  debouncerS1.update();
  static int lastBtnS1Val = -1;
  int BtnS1Val = debouncerS1.read();
  if (BtnS1Val != lastBtnS1Val) {
    lastBtnS1Val = BtnS1Val;
    if ( BtnS1Val == HIGH ) {
      // evento Release
      return evtS1Release;
    }
    else {
      // evento Press
      return evtS1Press;
    }
  }

  // evento encostar a argola no ponto final
  debouncerS2.update();
  static int lastBtnS2Val = -1;
  int BtnS2Val = debouncerS2.read();
  if (BtnS2Val != lastBtnS2Val) {
    lastBtnS2Val = BtnS2Val;
    if ( BtnS2Val == HIGH ) {
      // evento Release
      return evtS2Release;
    }
    else {
      // evento Press
      return evtS2Press;
    }
  }

  getSoundVolume();

  return -1;
}

// mostra os jogados ativos no jogo e a sequencia deles
void displayPlayers() {
  digitalWrite(BACKLIGHT_PIN, HIGH);
  lcd.clear();
  lcd.setCursor(0, 0);
  displayRomStr(10120);     // Ordem dos jogadores
  lcd.setCursor(0, 1);
  lcd.write("1-");
  lcd.write(players[0]);
  lcd.setCursor(11, 1);
  lcd.write("2-");
  lcd.write(players[1]);
  if (NumberPlayers > 2) {
    lcd.setCursor(0, 2);
    lcd.write("3-");
    lcd.write(players[2]);
  }
  if (NumberPlayers > 3) {
    lcd.setCursor(11, 2);
    lcd.write("4-");
    lcd.write(players[3]);
  }
  if (NumberPlayers > 4) {
    lcd.setCursor(0, 3);
    lcd.write("5-");
    lcd.write(players[4]);
  }
}

// apaga todos os leds
void turnOffAllLeds() {
  lc.shutdown(0, false);
  lc.clearDisplay(0);
}

// faz os leds da roleta acenderem sequencialmente
// com velocidade indicada pelo valor do rotary encoder.
void spinRoulette() {
  int randNumber = random(20);

  digitalWrite(BACKLIGHT_PIN, LOW);

  int turns = randNumber + (encoderValue * 2);
  int i = 0;
  int speed = 180 - (encoderValue * 10);
  if (speed < 10) speed = 10;

  while (i <= turns) {
    ligaLed(roulettePos, true);
    delay(speed);
    speed = speed + 1;
    ligaLed(roulettePos, false);
    roulettePos++;
    if (roulettePos > 16) {
      roulettePos = 1;
    }
    i++;
  }

  int rv = rouletteVal[roulettePos - 1];

  // evita que o jogador atual sofra a penalidade
  // de voltar ao início mais de uma vez
  if (rv == -1) {
    if (playersPenalty[currentPlayer] > 0) {
      roulettePos++;
      rv = rouletteVal[roulettePos - 1];
    }
    playersPenalty[currentPlayer]++;
  }

  ligaLed(roulettePos, true);
  digitalWrite(BACKLIGHT_PIN, HIGH);
}

// mostra o placar geral, com a posição
// no tabuleiro de cada jogador
void displayPos() {
  digitalWrite(BACKLIGHT_PIN, HIGH);
  lcd.clear();
  lcd.setCursor(0, 0);
  displayRomStr(10140);     // Placar geral:

  lcd.setCursor(0, 1);
  lcd.write(players[0]);
  char str[10];
  sprintf(str, " %2d", playersPos[0]);
  lcd.setCursor(10, 1);
  lcd.write(str);

  if (NumberPlayers > 1) {
    lcd.setCursor(0, 2);
    lcd.write(players[1]);
    char str[10];
    sprintf(str, " %2d", playersPos[1]);
    lcd.setCursor(10, 2);
    lcd.write(str);
  }
  if (NumberPlayers > 2) {
    lcd.setCursor(0, 3);
    lcd.write(players[2]);
    char str[10];
    sprintf(str, " %2d", playersPos[2]);
    lcd.setCursor(10, 3);
    lcd.write(str);
  }

  if (NumberPlayers > 3) {
    waitConfirm(3000);
    lcd.clear();
    lcd.setCursor(0, 0);
    lcd.write(players[3]);
    char str[10];
    sprintf(str, " %2d", playersPos[3]);
    lcd.setCursor(10, 0);
    lcd.write(str);
  }

  if (NumberPlayers > 4) {
    lcd.setCursor(0, 1);
    lcd.write(players[4]);
    char str[10];
    sprintf(str, " %2d", playersPos[4]);
    lcd.setCursor(10, 1);
    lcd.write(str);
  }

  buttonPressed = -1;
  waitConfirm(3000);
}

// mostra a mensagem de fim de jogo
void displayGameOver() {
  digitalWrite(BACKLIGHT_PIN, HIGH);
  lcd.clear();
  lcd.setCursor(0, 1);
  displayRomStr(10160);     // game over
  waitConfirm(0);
}


// exibe uma questao aleatoria, lendo da memoria EEPROM ------------------
#define eepromChip 0x50    //romAddress of 24LC256 eeprom chip
#define recCount 47
#define recordLength 160
#define fieldLength   20
// questions in EEPROM
#define questLevel01_begin  0
#define questLevel01_end   13
#define questLevel02_begin 14
#define questLevel02_end   32
#define questLevel03_begin 33
#define questLevel03_end   46

// exibe a mensagem para o jogador retirar uma carta
// e indicar, através dos botões, a cor dela.
void displayGetCard() {
  loadChars(strAccents);
  digitalWrite(BACKLIGHT_PIN, HIGH);
  lcd.clear();
  displayPlayer();
  lcd.setCursor(0, 1);
  displayRomStr(10480);     // deve pegar uma carta
  lcd.setCursor(0, 2);
  displayRomStr(10500);     // e pressionar o botao
  lcd.setCursor(0, 3);
  displayRomStr(10520);     // da mesma cor.

  // espera a resposta
  ligaLed(ledButtonA, true);
  ligaLed(ledButtonB, true);
  ligaLed(ledButtonC, true);

  buttonPressed = -1;
  int level = 0;

  while (true)
  {
    buttonPressed = getButton();

    if (buttonPressed == 1) {  // botao vermelho = pergunta dificil
      level = 3;
      buttonPressed = -1;
      break;
    }
    if (buttonPressed == 2) {  // botao azul = pergunta media
      level = 2;
      buttonPressed = -1;
      break;
    }
    if (buttonPressed == 3) {  // botao verde = pergunta facil
      level = 1;
      buttonPressed = -1;
      break;
    }
    buttonPressed = -1;
  }

  lcd.clear();
  lcd.write("O ");
  displayPlayer();
  lcd.setCursor(0, 1);
  displayRomStr(10540);     // deve responder a
  lcd.setCursor(0, 2);
  displayRomStr(10560);     // pergunta a seguir:

  displayQuestion(level);
}
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

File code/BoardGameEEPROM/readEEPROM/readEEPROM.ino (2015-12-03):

#include <Wire.h>
#define eeprom1 0x50    //Address of 24LC256 eeprom chip
#define recCount 47
#define linesCount 47*8

#define recordLength 160
#define fieldLength   20

unsigned char rdata[21];
char xdata[21];

unsigned int addr = 0;

void setup(void)
{
  Serial.begin(9600);
  Wire.begin();

 
    //addr = 328;
    //writeEEPROM(eeprom1, addr, "*");
    //addr = 320;
    //readEEPROM(eeprom1, addr, rdata, fieldLength);
    //strncpy(xdata, (char*)rdata, fieldLength);
    //Serial.println(xdata);
  //updateData();
  //return;

  Serial.println("DATA READ");
  addr = 0;
  for (int i = 0; i < linesCount; i++) {
    readEEPROM(eeprom1, addr, rdata, fieldLength);
    strncpy(xdata, (char*)rdata, fieldLength);

    char strAddr[8];
    sprintf(strAddr, "%05d", addr);
    Serial.print(strAddr);
    Serial.print(char(9));
    Serial.println(xdata);

    addr = addr + fieldLength;
    delay(10);
  }
}

void loop() {
}

// atualiza os valores de espera entre as perguntas e as alternativas
char* t[]={ 
  "02","03","02","02","03","04","02","03","02","04",
  "02","04","03","03","03","03","03","02","03","02",
  "04","04","03","03","03","02","03","04","03","05",
  "03","04","04","03","04","02","03","03","02","02",
  "03","03","03","02","02","04","05"
};
void updateData() {
  Serial.println("DATA UPDATE");
  addr = 0;
  for (int i = 0; i < recCount; i++) {
    writeEEPROM(eeprom1, addr+5, t[i]);

    readEEPROM(eeprom1, addr, rdata, fieldLength);
    strncpy(xdata, (char*)rdata, fieldLength);
    
    char strAddr[8];
    sprintf(strAddr, "%05d-", addr);
    Serial.print(strAddr);
    Serial.print(xdata);
    Serial.println();

    addr = addr + recordLength;
    delay(10);
  }
}



void writeEEPROM(int deviceaddress, unsigned int eeaddress, char* data)
{
  // Uses Page Write for 24LC256
  // Allows for 64 byte page boundary
  // Splits string into max 16 byte writes
  unsigned char i = 0, counter = 0;
  unsigned int  address;
  unsigned int  page_space;
  unsigned int  page = 0;
  unsigned int  num_writes;
  unsigned int  data_len = 0;
  unsigned char first_write_size;
  unsigned char last_write_size;
  unsigned char write_size;

  // Calculate length of data
  do {
    data_len++;
  }
  while (data[data_len]);

  // Calculate space available in first page
  page_space = int(((eeaddress / 64) + 1) * 64) - eeaddress;

  // Calculate first write size
  if (page_space > 16) {
    first_write_size = page_space - ((page_space / 16) * 16);
    if (first_write_size == 0) first_write_size = 16;
  }
  else
    first_write_size = page_space;

  // calculate size of last write
  if (data_len > first_write_size)
    last_write_size = (data_len - first_write_size) % 16;

  // Calculate how many writes we need
  if (data_len > first_write_size)
    num_writes = ((data_len - first_write_size) / 16) + 2;
  else
    num_writes = 1;

  i = 0;
  address = eeaddress;
  for (page = 0; page < num_writes; page++)
  {
    if (page == 0) write_size = first_write_size;
    else if (page == (num_writes - 1)) write_size = last_write_size;
    else write_size = 16;

    Wire.beginTransmission(deviceaddress);
    Wire.write((int)((address) >> 8));   // MSB
    Wire.write((int)((address) & 0xFF)); // LSB
    counter = 0;
    do {
      Wire.write((byte) data[i]);
      i++;
      counter++;
    }
    while ((data[i]) && (counter < write_size));
    Wire.endTransmission();
    address += write_size; // Increment address for next write

    delay(6);  // needs 5ms for page write
  }
}

void readEEPROM(int deviceaddress, unsigned int eeaddress, unsigned char* data, unsigned int num_chars)
{
  unsigned char i = 0;
  Wire.beginTransmission(deviceaddress);
  Wire.write((int)(eeaddress >> 8));   // MSB
  Wire.write((int)(eeaddress & 0xFF)); // LSB
  Wire.endTransmission();

  Wire.requestFrom(deviceaddress, num_chars);

  while (Wire.available()) data[i++] = Wire.read();

}

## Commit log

2015-12-03 BoardGame
    Egypt-themed board game powered by an Arduino Nano
2018-12-21 Fritzing project
    [BoardGame.fzz]
2018-12-21 BOM & PCB
    [BOM.xlsx]
